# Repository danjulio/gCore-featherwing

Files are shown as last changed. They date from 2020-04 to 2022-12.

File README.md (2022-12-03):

Note: Check out my second version of [gCore](https://github.com/danjulio/gCore).

## gCore - A controller for portable GUI-based devices
gCore ("Gadget Core") is an ESP32 development board designed to mate with the [Adafruit TFT Featherwing](https://www.adafruit.com/product/3651) 480x320 pixel 3.5" TFT LCD display with resistive touch.  It contains a WROVER-B module, USB UART, true USB power-bath Li-Ion battery charger, a pair of ICR10440 batteries and a boost/buck 3.3V converter.  It is designed to support soft-power control and battery voltage/charge status monitoring.  A write-up exists on [hackaday.io](https://hackaday.io/project/170774-old-gcore-for-gui-based-gadgets).

gCore is released as open source hardware and supporting software under the GPLv3 license in hopes it will be helpful to others.  This repository contains two subdirectories.

1. hardware - contains eagle design files, gerber files, and documentation.
2. software - arduino library for power control, [LittlevGL](https://github.com/littlevgl) driver for Arduino and [FabGL](https://github.com/fdivitto/FabGL) port.

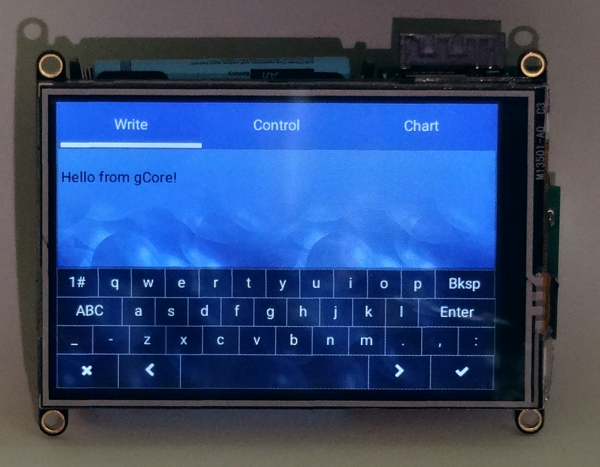
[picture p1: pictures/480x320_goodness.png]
gCore LittlevGL


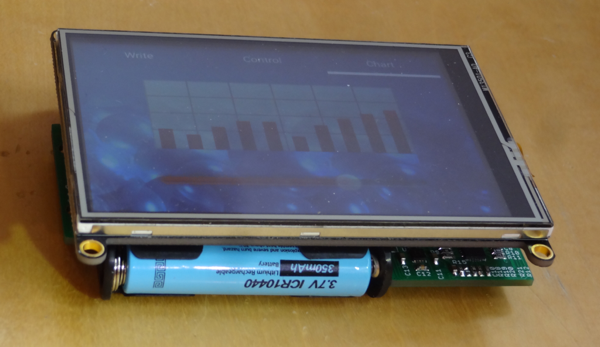
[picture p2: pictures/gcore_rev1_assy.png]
gCore


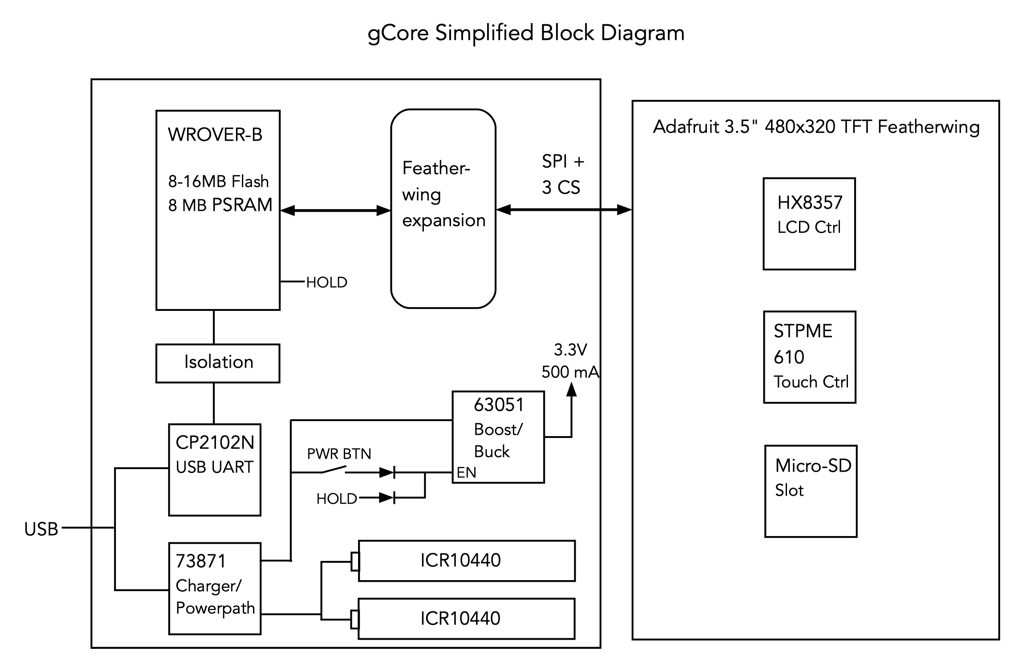
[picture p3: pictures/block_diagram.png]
gCore Block Diagram


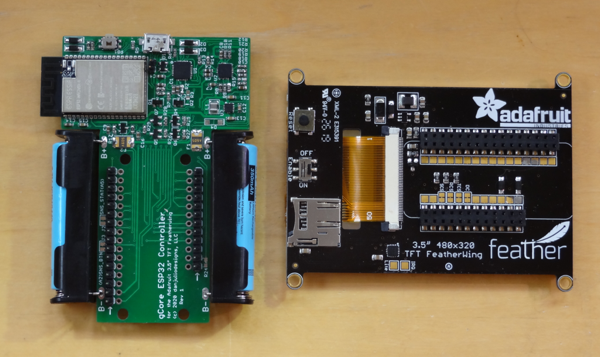
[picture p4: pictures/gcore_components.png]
gCore Components


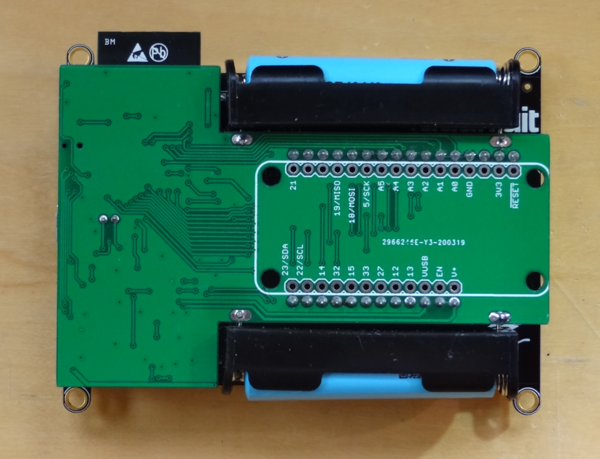
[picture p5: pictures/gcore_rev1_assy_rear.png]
gCore Rear


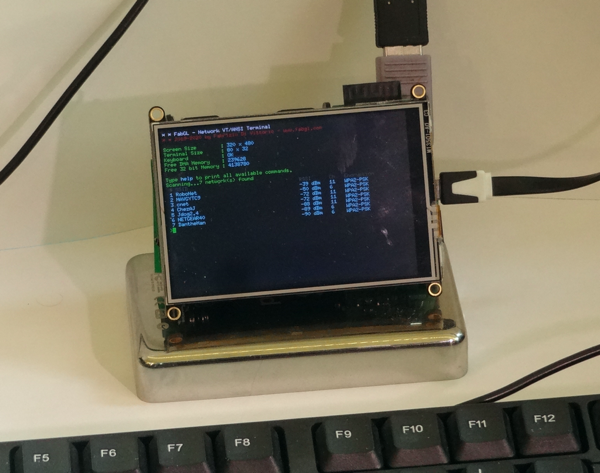
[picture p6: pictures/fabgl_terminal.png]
gCore FabGL


### gCore Operation
gCore is built around several components.

#### ESP32 Core
The ESP32 is a great micro-controller.  Powerful and inexpensive with a good amount of memory, WiFi, Bluetooth and full complement of peripherals.  Code can be written using Espressif's ESP IDF libraries and development environment or the ESP32 Arduino integration.  gCore uses a WROVER module because it also includes an external 8 MB PSRAM and up to 16 MB built-in flash enabling applications that require a lot of memory at the cost of two IO pins.

#### CP2102N USB UART
A Silicon Labs CP2102N USB UART provides access to the primary ESP32 serial port for programming and debug.  The RTS# and DTR# signals are interfaced to RESET# and IO0 in the traditional way so that external programming software can automatically upload new firmware.  While the ESP32 and other gCore devices are powered from its built-in power system, the CP2102 is powered by the USB port so that it does not add an additional load on the battery.  There is isolation circuitry to reduce sneak current paths between the two power domains.

The CP2102N CHRGEN and CHR0 signals are routed to the MCP73871 to allow for intelligent charge control based on the USB state.  These signals allow it to select a charge current of 0 mA when the USB Bus has been suspended (e.g. laptop sleeping), 100 mA when the USB Bus is running but the USB UART hasn't been enumerated yet or 500 mA when the USB Bus has been enumerated or gCore is connected to a dedicated USB Charger.  These features require the CP2102N be configured using software from Silicon Labs.  Please see the instructions in the Software/CP2102N subdirectory.

#### MCP73871 Load Sharing Charge Controller
A Microchip MCP73871 provides both the battery charging circuit and an intelligent power path that automatically routes power from USB, when available, to the Boost-Buck converter, augmenting it with power from the batteries when necessary.  This allows it to correctly identify when the batteries are charged (a problem with some other development boards that put the load on the same output that is charging the battery).  In addition the charge status signals are connected to a voltage divider network allowing the ESP32 to use an analog input to detect which of four states the charger is in.

* Charge Idle - Not charging.  Power either from USB or battery.
* Charging - Currently charging the battery
* Charge Done - Charging phase finished.  Power from USB.
* Fault - Charger detected a fault (see the spec sheet).

#### TPS63051 Boost-Buck Converter
A TI TPS63051 boost-buck converter provides gCore's 3.3V power supply at up to 500 mA.  Unlike many other development boards that only use a buck-converter (or inefficient linear regulator), it assures a valid 3.3V power supply even when the battery is depleted.  

#### Dual ICR10440 Li-Ion batteries
A pair of AAA-sized Li-Ion batteries allow for relatively thin enclosures.  The batteries are connected in parallel with each battery in series with a PTC to allow them to equalize during charge and discharge and protect from shorts.  They are capable of powering a device for a couple of hours of run-time.  Quality ICR10440 cells can be found on Amazon.  Since the charger can provide up to 450-500 mA when gCore is powered down always use two cells so the per-cell charge current doesn't exceed its recommended maximum.

A larger battery may also be used by connecting it to the terminals of one of the ICR10440 batteries.

**Update: See the note in the Hardware directory readme about issues with the dual battery system.** 

#### GPIO Utilization
| GPIO | Function | Notes |
|:----:|:---:|:-----:|
| IO5  |  SPI SCK | SPI CLK for TFT, Touchscreen and Micro-SD |
| IO14 | SD CS  | Micro-SD CS# on Adafruit TFT Featherwing |
| IO15 |  TFT CS  | TFT CS# on Adafruit TFT Featherwing |
| IO18 | SPI MOSI | SPI MOSI for TFT, Touchscreen and Micro-SD |
| IO19 | SPI MISO | SPI MISO for Touchscreen and Micro-SD |
| IO32 | TS CS  | Touchscreen CS# on Adafruit TFT Featherwing |
| IO33 |  TFT DC  | TFT DC on Adafruit TFT Featherwing |
| IO34 | SNS_BTN  | ESP ADC1_CH6/Arduino A2 Button sense analog input |
| IO35 | SNS_BATT | ESP ADC1_CH7 Battery voltage sense analog input |
| IO36 | SNS_STAT | ESP ADC1_CH0/Arduino A4 charge stat sense analog input |

Note that both the SNS\_BTN and SNS\_STAT signals include jumper pads with a cuttable link to disconnect them from the analog input in case their functionality is not needed or the analog input needs to be used for another purpose.  See the schematic in the hardware sub-directory for more detail.

The two featherwing signals normally used to bring out the second ESP32 UART on its IO16 and IO17 pins are not connected because these pins are used internally by the WROVER module to support the PSRAM.

IO14 is available if no Micro-SD Card is inserted into the TFT Featherwing.

#### Available GPIO
The following GPIO are not connected and are available for application use.

| GPIO | Notes |
|:----:|:-----:|
| IO4  | A5 |
| IO12 | |
| IO13 | |
| IO21 | |
| IO22 | SCL |
| IO23 | SDA |
| IO25 | A1 |
| IO26 | A0 |
| IO27 | |
| IO39 | A3 |

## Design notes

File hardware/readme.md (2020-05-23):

## gCore Hardware Documentation

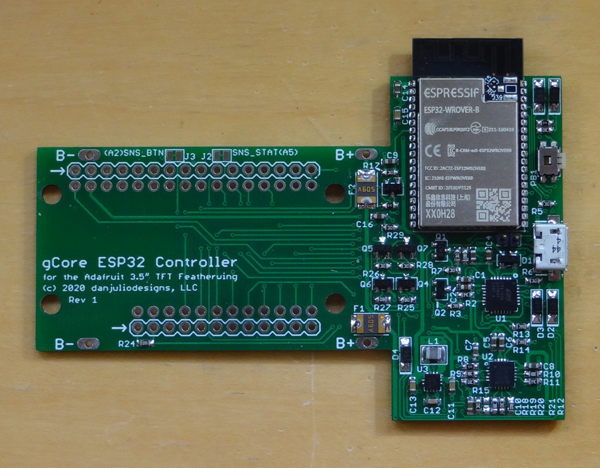
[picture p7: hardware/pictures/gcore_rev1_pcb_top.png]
gCore Rev 1 PCB


This directory contains the hardware design for gCore (Rev 2 design).

* documentation - BOM, schematic and board layout PDF renders, list of components to be loaded on the PCB.
* eagle - Eagle v7.7 design files
* gerber - Gerber files for PCB (not including stencil)
* stencil - Gerber files for top stencil

### Revision 2 Design Important Note
These files represent the second revision of the design.  To date I have only built the first revision and incorporated a few changes I found in Rev 2.  The changes were minor and I tested all of them with modifications (bodges) to the first revision. I am very confident that the second revision is correct and will work perfectly but in the spirit of full disclosure I'm letting you know.

#### Rev 2 PCB Top

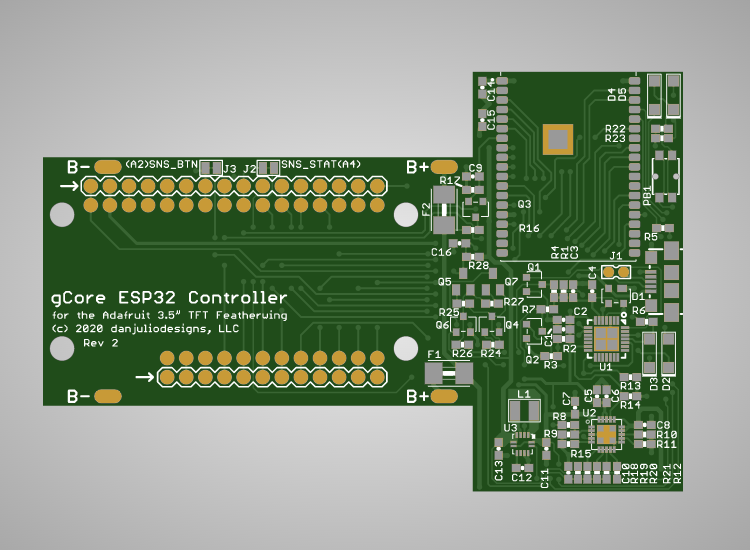
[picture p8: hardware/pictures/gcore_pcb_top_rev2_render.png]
Rev 2 PCB Top


#### Rev 2 PCB Bottom

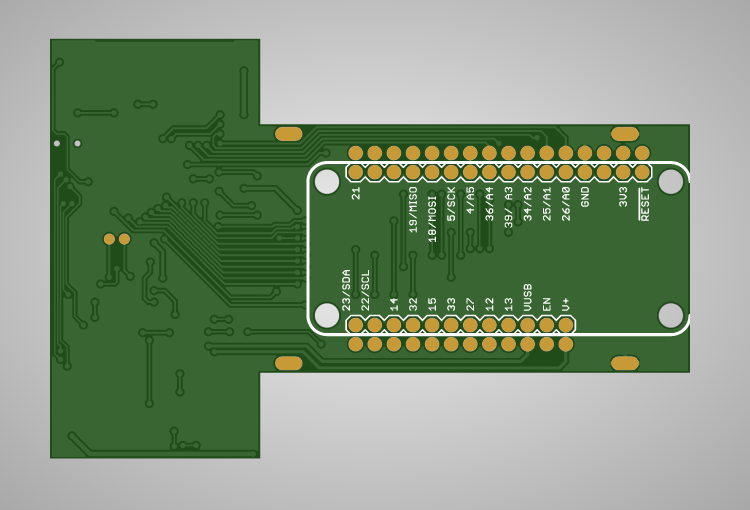
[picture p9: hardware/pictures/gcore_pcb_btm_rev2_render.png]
Rev 2 PCB Bottom


### Hardware Notes

1. Turn the power switch located on the Adafruit TFT LCD featherwing to the ON position.  This allows the LCD backlight to be lit when 3.3V power comes on and also provides the ability to use the GPIO2 output on the STMPE610 touchscreen controller to turn it on and off under software control.

2. The CHREN and CHR0 signals between U1 (CP2102N) and U2 (MCP73871) are designed to work in conjunction with reconfiguring U1 via Simplicity Studio Xpress Configurator to support USB Charger detection.  Do not stuff R13 and R14 if you will not reconfigure U1.  This enables charging  at 500 mA.

2. Cut J3 between the pads if you do not want the power button sense circuitry attached to an analog input or you wish to attach it to a different analog input (connect a wire from the right pad to the desired analog input).

4. Cut J4 between the pads if you do not want the charge status sense circuitry attached to an analog input or you wish to attach it to a different analog input (connect a wire from the right pad to the desired analog input).

5. Two pins (J6-14, J6-15) on the featherwing expansion port are not connected.  On Sparkfun and Adafruit ESP32 featherwings these are connected to ESP32 GPIO 16 and 17.  However these pins are not available on the gCore's WROVER-B module.  They are used internally for the 8 MB PSRAM.

6. J1 is an optional jumper between the two USB data lines.  It should not be necessary and was included in case you ever attach a power supply to gCore that does not short the data lines.  The CP2102N will enable charging because it thinks the bus is not enumerated and there is no charger attached.  But be sure to remove the jumper before connecting to a computer!

### Battery Notes
After using a pair of gCore prototypes for some time I found that one unit would no longer keep the batteries balanced and they would slowly discharge.  The other unit works fine.  Experimentation described in more detail on the hackaday.io project page was unsuccessful in explaining why so now I must add the caveat that using the dual ICR10440 battery solution may not work.  It's easy, however, to use a single battery, connected to one pair of battery terminals, with its PTC bypassed, and the AAA battery holders removed or not installed.

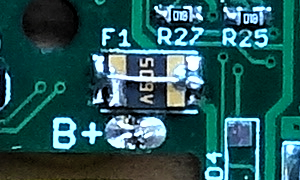
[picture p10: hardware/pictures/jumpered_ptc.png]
Jumpered PTC


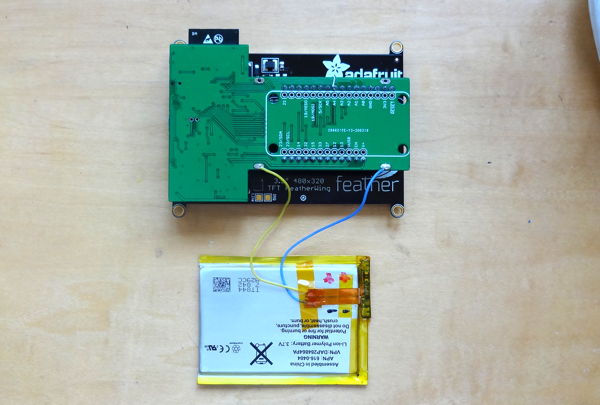
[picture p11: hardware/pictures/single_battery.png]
Single battery


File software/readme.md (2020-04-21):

## gCore software support

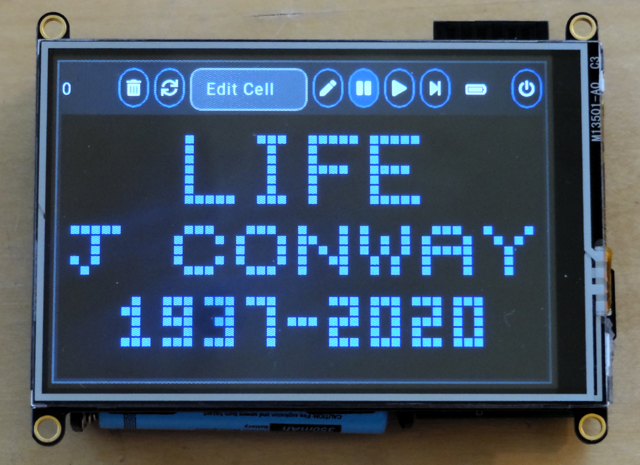
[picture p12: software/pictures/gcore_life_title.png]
Demo tribute to John Conway


This directory contains software support for gCore to provide TFT and touchscreen drivers and power management functions for both Arduino and ESP IDF development environments.  See each subdirectory for more information.

* Arduino - A pair of demos for ESP32 Arduino including gCore power management and [LittlevGL/Arduino](https://github.com/littlevgl/lv_arduino) integration.
* CP2102N - Instructions for enabling automatic USB charger detection in the Silicon Labs CP2102N USB UART.  This allows gCore to correctly set charge current levels based on the USB interface.
* FabGL - A port of Fabrizio Di Vittorio's fantasic [FabGL](https://github.com/fdivitto/FabGL) library to gCore.
* LittlevGL - A native v3.5 ESP-IDF demo project showing [Native LittlevGL](https://github.com/littlevgl/lvgl) integration.

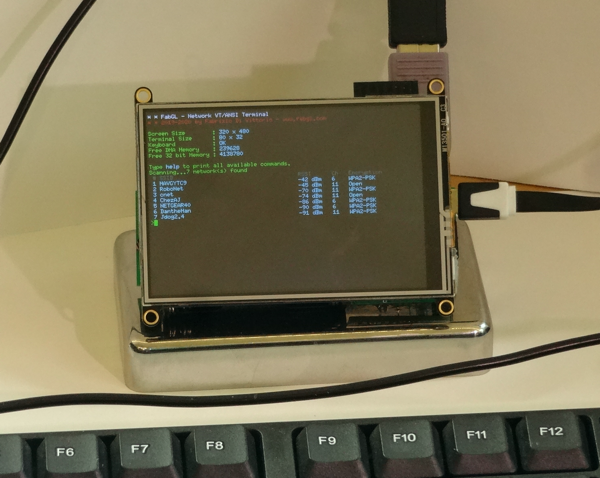
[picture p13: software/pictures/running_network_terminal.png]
A tiny VT100


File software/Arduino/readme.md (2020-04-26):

## gCore ESP32 Arduino

Two simple demos showing how to integrate gCore into ESP32 Arduino projects.  You will need to add ESP32 support to Arduino (see links below).

1. `gcore_power_demo` - Simple sketch that includes `gcore_power.ino` for power management (see below).  The sketch simply prints battery voltage, button press detection (short/long press) and charge state every second.  After 60 seconds a long press will power off (when the button is released).  After 120 seconds the sketch powers down automatically.

2. `lvgl_demo` - A port of the LittlevGL demo to arduino.  This sketch includes `tft.ino` and `ts.ino` along with the driver integration code for the Arduino version of LittlevGL to use the Adafruit TFT/touchscreen.  The demo also uses `gcore_power.ino` to provide automatic low-battery shutdown and shutdown on a long power button press.  You will need to add the LittlevGL library to Arduino.  I used v6.1.1 during development.

### Useful Links

* [Esspressif ESP32 Arduino github](https://github.com/espressif/arduino-esp32)
* [LittlevGL Arduino github](https://github.com/littlevgl/lv_arduino)

### gcore_power module API
The ```gcore_power``` module creates a separate FreeRTOS task to read the three analog inputs connected to gCore circuitry (battery voltage, button, and charge state), keep power-management related state and provide an API for use by user Arduino code (protected by a mutex).

`gcore_set_btn_pin(pin)` - Used to set a non-standard GPIO pin for the button analog input (if you cut J3 and wire to another analog input).  Call this before calling ```gcore_begin()```.  Does not need to be called to use the default input.

`gcore_set_stat_pin(pin)` - Used to set a non-standard GPIO pin for the status analog input (if you cut J4 and wire to another analog input).  Call this before calling `gcore_begin()`.  Does not need to be called to use the default input.
 
`gcore_begin()` - Initialize the power monitoring system.  Should be called during setup before calling other API routines (aside from the set_pin routines above).

`gcore_get_batt_voltage()` - Returns a float with the current battery voltage.  Note that the ESP32 internal vref is not highly precise and although the Arduino library attempts to use any built-in calibration constants this reading can be off by 100mV or so.

`gcore_set_low_voltage_threshold(volts)` - Set the automatic low-battery shutdown voltage specifying a float between 2.5 an 4.2.  The default is 3.4 volts.

`gcore_get_low_voltage_threshold()` - Returns a float with the current automatic low-battery shutdown voltage.

`gcore_set_low_voltage_duration(secs)` - Set the automatic low-battery shutdown interval specifying an integer number of seconds the battery voltage must be below the low voltage threshold.  The default is 10 seconds.

`gcore_get_low_voltage_duration()` - Returns an integer containing the automatic low-battery shutdown interval.

`gcore_button_down()` - Returns a bool indicating if the power button is currently detected in the pressed state.

`gcore_button_short_press()` - Returns a bool indicating if a short-press has been detected.  A short-press is detected when the power button is pressed and released before the button threshold seconds have elapsed.

`gcore_button_long_press()` - Returns a bool indicating if a long-press has been detected.  A long-press is detected when the power button is pressed at the point button threshold seconds have elapsed.

`gcore_set_button_shutdown_enable(en)` - Enable or disable power-off when a long-press is detected by passing in a true or false bool value.  When enabled power will be disabled when the power button is held for the button threshold seconds.  Note that because the button circuitry enables power while the button is pressed power will not actually be removed until the button is released.  This function enables the code to de-assert PWR_HOLD.  Power button power-off functionality is enabled by default.

`gcore_get_button_shutdown_enable()` - Returns a bool indicating if power button power-off functionality is enabled or not.

`gcore_set_button_threshold_duration(secs)` - Set the button threshold integer seconds used to differentiate between short and long press.  The default value is 2 seconds.

`gcore_get_button_threshold_duration()` - Return and integer containing the button threshold seconds.

`gcore_get_charge_state()` - Returns an integer indicating the current charge state.

* 0 - Charge Idle.  No external power source connected.
* 1 - Charge Complete.  Not charging but external power source connected.
* 2 - Charging.
* 3 - Charge Fault (see the MCP73871 specification).

`gcore_power_down()` - De-assert the PWR_HOLD signal to immediately powerdown gCore.

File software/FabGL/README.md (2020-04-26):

# FabGL

## gCore Modifications
This directory contains the modified FabGL code to work with gCore.  Primarily this includes adding support for the HX8357 TFT driver.  I had to modify FabGL to support a higher resolution TFT display (480x320) that included a new buffer scheme because the existing software architecture caused the ESP32 to run out of memory at that resolution; as well as modify the terminal to support more than 25 lines.

* `src/fabglconf.h` - Added a modeline for 480x320 pixel TFT display.
* `src/terminal.cpp` - Added support for a maximum of 32 lines.
* `src/dispdrivers/TFTControllerGeneric.cpp` - Many changes including reducing SPI frequency to 26 MHz and modifying the SPI transactions, changing malloc allocation to use a different buffer scheme and fixing a bug in the TFT orientation code.
* `src/dispdrivers/TFTControllerGeneric.h` - Added new DMA buffer.
* `src/dispdrivers/TFTControllerSpecific.cpp` - Added support for HX8357 TFT driver.
* `src/dispdrivers/TFTControllerSpecific.h` - Added support for HX8357 TFT driver.

The examples in this directory were ported to gCore.  I used GPIO13 for PS/2 keyboard data and GPIO27 for PS/2 keyboard clock wired the way Fabrizio recommends.  The examples here also include the gCore power management functionality with automatic low-battery shutdown and soft power off by pressing and holding the power button.

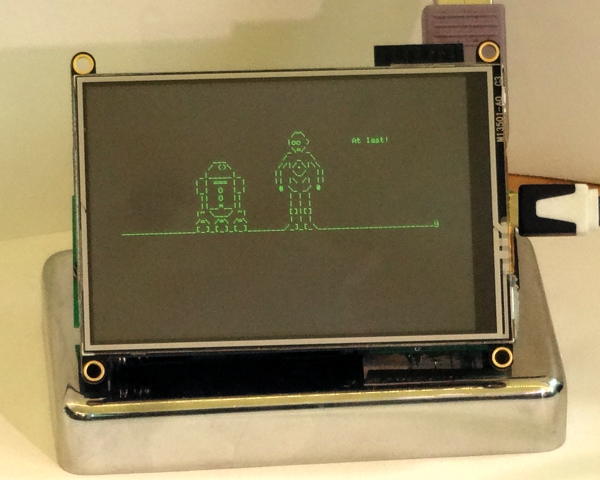
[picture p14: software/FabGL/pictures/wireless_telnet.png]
A very famous telnet


## Original FabGL README contents
### Display Controller, PS/2 Mouse and Keyboard Controller, Graphics Library, Sound Engine, Graphical User Interface (GUI), Game Engine and ANSI/VT Terminal for the **ESP32**

**[Please look here for full API documentation](http://www.fabglib.org)**

If you would like to **support FabGL's development**, please see the [**Donations page**][Donations].
You can also support me getting my own [development board](https://www.tindie.com/products/fabgl/fabgl-development-board/).

This library works with ESP32 revision 1 or upper. See [**Compatible Boards**][Boards].

FabGL is mainly a Graphics Library for ESP32. It implements several display drivers (for direct VGA output and for I2C and SPI LCD drivers).
FabGL can also get input from a PS/2 Keyboard and a Mouse. FabGL implements also: an Audio Engine, a Graphical User Interface (GUI), a Game Engine and an ANSI/VT Terminal.

This library works with ESP32 revision 1 and upper.

VGA output requires a digital to analog converter (DAC): it can be done by three 270 Ohm resistors to have 8 colors, or by 6 resistors to have 64 colors.

There are several fixed and variable width fonts embedded.

Unlimited number of sprites are supported. However big sprites and a large amount of them reduces the frame rate and could generate flickering.

When there is enough memory (on low resolutions like 320x200), it is possible to allocate two screen buffers, so to implement double buffering.
In this case primitives are always drawn on the back buffer.

Except for double buffering or when explicitly disabled, all drawings are performed on vertical retracing (using VGA driver), so no flickering is visible.
If the queue of primitives to draw is not processed before the vertical retracing ends, then it is interrupted and continued at next retracing.

There is a graphical user interface (GUI) with overlapping windows and mouse handling and a lot of widgets (buttons, editboxes, checkboxes, comboboxes, listboxes, etc..).

Finally, there is a sound engine, with multiple channels mixed to a mono output. Each channel can generate sine waveforms, square, etc... or custom sampled data.

### Installation Tutorial (click for video):

Everything Is AWESOME (https://www.youtube.com/watch?v=8OTaPQlSTas "")

### Space Invaders Example (click for video):

Everything Is AWESOME (https://www.youtube.com/watch?v=LL8J7tjxeXA "")

### Graphical User Interface - GUI (click for video):

Everything Is AWESOME (https://www.youtube.com/watch?v=84ytGdiOih0 "")

### Sound Engine (click for video):

Everything Is AWESOME (https://www.youtube.com/watch?v=RQtKFgU7OYI "")

### Altair 8800 emulator - CP/M text games (click for video):

Everything Is AWESOME (https://www.youtube.com/watch?v=y0opVifEyS8 "")

### Commodore VIC20 emulator (click for video):

Everything Is AWESOME (https://www.youtube.com/watch?v=ZW427HVWYys "")

### Simple Terminal Out Example (click for video):

Everything Is AWESOME (https://www.youtube.com/watch?v=AmXN0SIRqqU "")

### Network Terminal Example (click for video):

Everything Is AWESOME (https://www.youtube.com/watch?v=n5c27-y5tm4 "")

### Modeline Studio Example (click for video):

Everything Is AWESOME (https://www.youtube.com/watch?v=Urp0rPukjzE "")

### Loopback Terminal Example (click for video):

Everything Is AWESOME (https://www.youtube.com/watch?v=hQhU5hgWdcU "")

### Double Buffering Example (click for video):

Everything Is AWESOME (https://www.youtube.com/watch?v=TRQcIiWQCJw "")

### Collision Detection Example (click for video):

Everything Is AWESOME (https://www.youtube.com/watch?v=q3OPSq4HhDE "")

[Donations]: https://github.com/fdivitto/FabGL/wiki/Donations
[Boards]: https://github.com/fdivitto/FabGL/wiki/Boards

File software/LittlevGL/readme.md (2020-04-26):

## gCore native LittlevGL Demo
This demo shows native LittlevGL integration along with a version of the gCore power management functions into the native Esspressif IDF.  It is based on the [ESP32 port of LittlevGL](https://github.com/littlevgl/lv_port_esp32).  Along with the demo application the gCore specific parts include the TFT and Touchscreen drivers and power management functions.

[John Conway](https://en.wikipedia.org/wiki/John_Horton_Conway), father of the Game of Life program, passed away due to complications from the COVID-19 virus while I was deciding what demo to write to show off gCore and LittlevGL.  This demo is my tribute to him and his many contributions to the fields of mathematics and computer science.

I built this demo using v3.5 of the [ESP IDF](https://github.com/espressif/esp-idf).  It should compile with no or few changes in the v4.X version.  It uses various LittlevGL controls such as buttons, drop-down menu, labels and canvas.  It's best used with a plastic pointer designed for resistive touch screens (especially when editing individual cells).

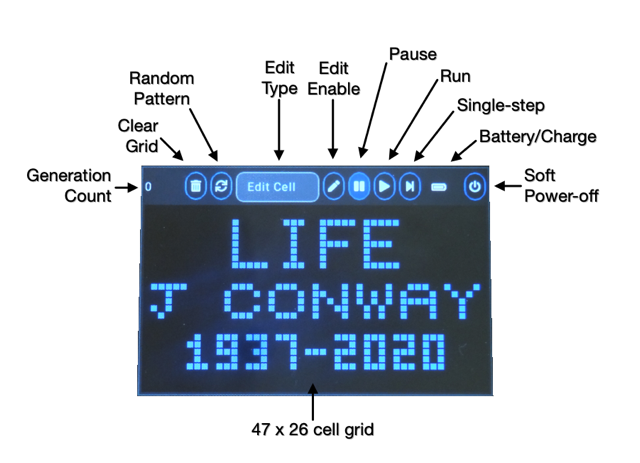
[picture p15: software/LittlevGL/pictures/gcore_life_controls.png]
gCore Life Controls


gCore Life implements Conway's original [Life](https://en.wikipedia.org/wiki/Conway%27s_Game_of_Life) algorithm.  It also includes a bunch of classic life cell collections that made interesting objects such as "gliders", a "glider gun", "spaceships" and more that can be added to the grid.  It's pretty demanding of the LittlevGL rendering system and gets about 6 generations/second although the actual Life alorithm is very fast.

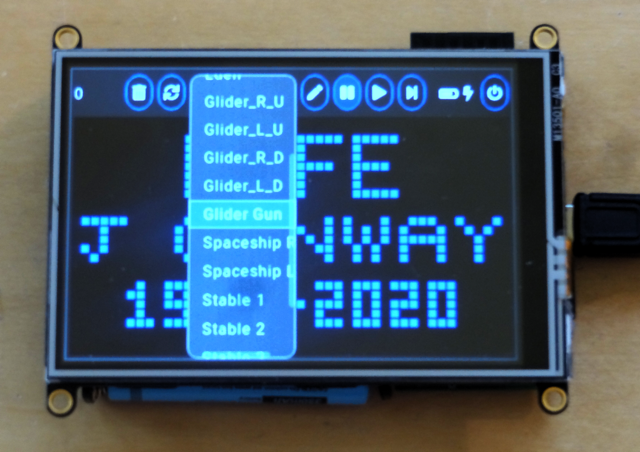
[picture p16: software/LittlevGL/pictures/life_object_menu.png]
Life Object menu


A "glider gun" above a left moving "spaceship".

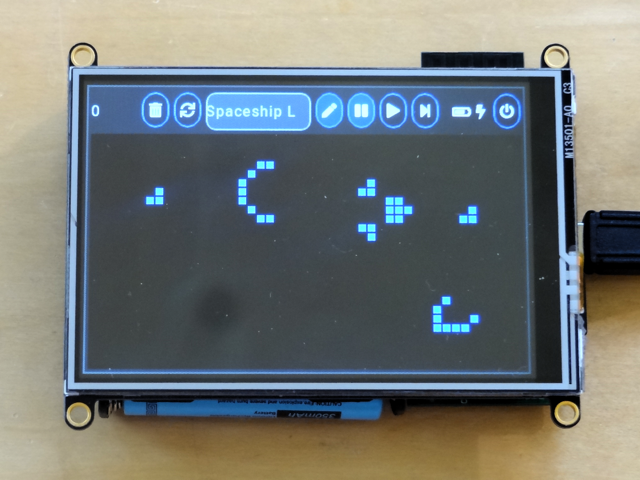
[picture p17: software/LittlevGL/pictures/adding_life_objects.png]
About to blow away a spaceship


### gCore power management functions
These functions are almost identical to those documented in the Arduino directory of this repository.  The only change is that `gcore_get_charge_state()` returns a `gcore_charge_t` enum value as shown in `gcore_power.h`.

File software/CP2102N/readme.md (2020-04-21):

## CP2102N Configuration
The Silicon Labs CP2102N USB UART used by gCore supports the ability to automatically identify USB Chargers and use that information along with information about the USB Bus enumeration (when plugged into a computer) to indicate the amount of current that legally can be taken from the USB bus on a pair of signals (CHREN and CH0).

* No current allowed - USB Suspended (e.g. laptop sleeping)
* 100 mA max - Un-enumerated USB Bus
* 500 mA max - Enumerated bus or USB Charger detected

These signals are connected to the MCP73871 charge controller on gCore (note: see the note in the hardware directory about how to enable charging if you do not reconfigure the CP2102N as shown here).  The charge controller is configured to supply a maximum of 0 mA, 100 mA or about 500 mA to both batteries for charging depending on the state of these signals.

Unfortunately this functionality is not enabled by default.  The instructions in the included Silicon Labs app note `AN721.pdf` show how to download and install a utility or the Simplicity Studio development environment that allows reconfiguration of the CP2102N via its USB interface and Silicon Labs Xpress Configurator.

The following changes need to be made via Xpress Configurator:

1. Reconfigure the maximum USB Current to 500 mA.
2. Enable Battery Charging functionality with a maximum current of 500 mA.

The images below show the changes I make to the default values read from the CP2102N by Xpress Configurator.

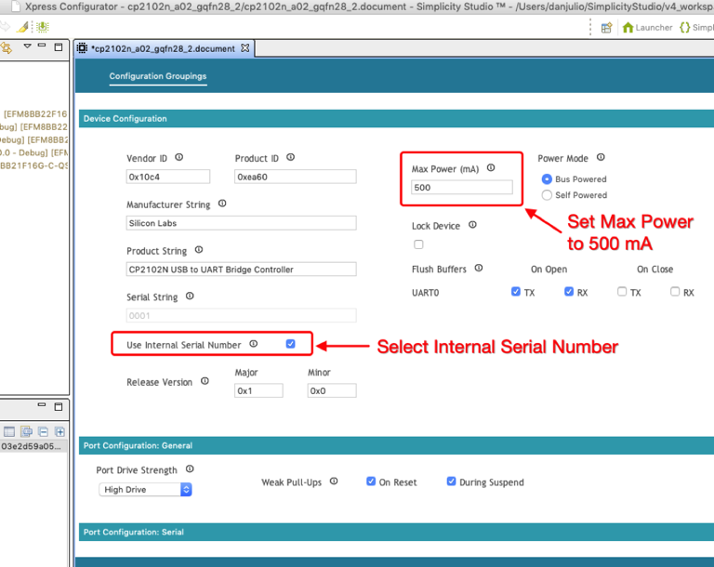
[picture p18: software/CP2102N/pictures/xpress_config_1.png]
First set of changes


For some reason the version of the Xpress Configurator I used from within Simplicity Studio did not automatically check the "User Internal Serial Number" button.  You need to do this if you wish to keep the factory-programmed serial number in each CP2102N.

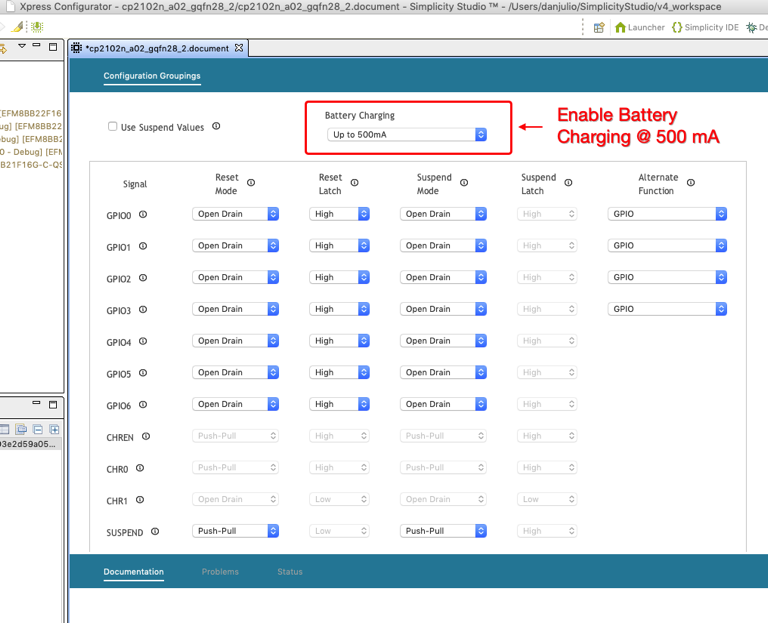
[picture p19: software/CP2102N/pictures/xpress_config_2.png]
Second set of changes


After making the changes it is a quick process to program them to the device.

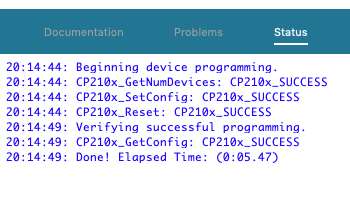
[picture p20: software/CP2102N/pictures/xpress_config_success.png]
programming success


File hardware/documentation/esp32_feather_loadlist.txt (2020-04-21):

ESP32 Featherwing Loadlist - Rev 2

Part     Value               Device               Package             Library             Sheet
A1       ESP32-WROVER-I      ESP32-WROVER-I       XCVR_ESP32-WROVER-I ESP32-WROVER-I      2

C1       4.7 uF              C-USSMT0603          C0603               djd_eagle_library   1
C3       4.7 uF              C-USSMT0603          C0603               djd_eagle_library   1
C5       4.7 uF              C-USSMT0603          C0603               djd_eagle_library   1
C6       4.7 uF              C-USSMT0603          C0603               djd_eagle_library   1
C7       4.7 uF              C-USSMT0603          C0603               djd_eagle_library   1
C8       4.7 uF              C-USSMT0603          C0603               djd_eagle_library   1

C2       0.1 uF              C-USSMT0603          C0603               djd_eagle_library   1
C4       0.1 uF              C-USSMT0603          C0603               djd_eagle_library   1
C9       0.1 uF              C-USSMT0603          C0603               djd_eagle_library   1
C10      0.1 uF              C-USSMT0603          C0603               djd_eagle_library   1
C14      0.1 uF              C-USSMT0603          C0603               djd_eagle_library   2
C16      0.1 uF              C-USSMT0603          C0603               djd_eagle_library   2

C11      22 uF               C-USSMT0603          C0603               djd_eagle_library   2
C13      22 uF               C-USSMT0603          C0603               djd_eagle_library   2
C15      22 uF               C-USSMT0603          C0603               djd_eagle_library   2

C12      1 nF                C-USSMT0603          C0603               djd_eagle_library   2

CON1                         USBMICROB            USB_MICROB_SMT      djd_eagle_library   1

D1       SP0503BAHTG         SP0503BAHTG          SOT143              djd_eagle_library   1

D2       SD103               DIODESMT_SOD123      SOD123              djd_eagle_library   1
D3       SD103               DIODESMT_SOD123      SOD123              djd_eagle_library   1
D4       SD103               DIODESMT_SOD123      SOD123              djd_eagle_library   2
D5       SD103               DIODESMT_SOD123      SOD123              djd_eagle_library   2

F1       MF-MSMF050          PTCFUSE-1812         1812                adafruit            1
F2       MF-MSMF050          PTCFUSE-1812         1812                adafruit            1

J1       332-02              332-02               332-02              con-garry           1

L1       1.5 uH              INDUCTORSMT1008      L1008               djd_eagle_library   2

PB1      436351045816        PB_TACT_4WS          WURTH_WS_TASU_TACT  djd_eagle_library   2

Q1       NX7002AKVL          MOSFET-NCHANNELSOT23 SOT23-3             djd_eagle_library   1
Q2       NX7002AKVL          MOSFET-NCHANNELSOT23 SOT23-3             djd_eagle_library   1
Q3       NX7002AKVL          MOSFET-NCHANNELSOT23 SOT23-3             djd_eagle_library   1
Q4       NX7002AKVL          MOSFET-NCHANNELSOT23 SOT23-3             djd_eagle_library   2
Q6       NX7002AKVL          MOSFET-NCHANNELSOT23 SOT23-3             djd_eagle_library   2

Q5       MMBT3904-7-F        BC808-NPN-SOT23-BEC  SOT23-BEC           transistor          2
Q7       MMBT3904-7-F        BC808-NPN-SOT23-BEC  SOT23-BEC           transistor          2

R1       1 kohm              R-USSMT0603          R0603               djd_eagle_library   1
R12      1 kohm              R-USSMT0603          R0603               djd_eagle_library   1
R24      1 kohm              R-USSMT0603          R0603               djd_eagle_library   2
R26      1 kohm              R-USSMT0603          R0603               djd_eagle_library   2

R2       22.1 kohm           R-USSMT0603          R0603               djd_eagle_library   1
R11      22.1 kohm           R-USSMT0603          R0603               djd_eagle_library   1

R3       47.5 kohm           R-USSMT0603          R0603               djd_eagle_library   1
R13      47.5 kohm           R-USSMT0603          R0603               djd_eagle_library   1
R14      47.5 kohm           R-USSMT0603          R0603               djd_eagle_library   1

R4       10 kohm             R-USSMT0603          R0603               djd_eagle_library   1
R5       10 kohm             R-USSMT0603          R0603               djd_eagle_library   1
R6       10 kohm             R-USSMT0603          R0603               djd_eagle_library   1
R7       10 kohm             R-USSMT0603          R0603               djd_eagle_library   1
R15      10 kohm             R-USSMT0603          R0603               djd_eagle_library   1
R17      10 kohm             R-USSMT0603          R0603               djd_eagle_library   1
R18      10 kohm             R-USSMT0603          R0603               djd_eagle_library   1
R21      10 kohm             R-USSMT0603          R0603               djd_eagle_library   1
R23      10 kohm             R-USSMT0603          R0603               djd_eagle_library   2
R25      10 kohm             R-USSMT0603          R0603               djd_eagle_library   2
R27      10 kohm             R-USSMT0603          R0603               djd_eagle_library   2
R28      10 kohm             R-USSMT0603          R0603               djd_eagle_library   2

R8       40.2 kohm           R-USSMT0603          R0603               djd_eagle_library   1
R16      40.2 kohm           R-USSMT0603          R0603               djd_eagle_library   1
R22      40.2 kohm           R-USSMT0603          R0603               djd_eagle_library   2

R9       15 kohm             R-USSMT0603          R0603               djd_eagle_library   1
R20      15 kohm             R-USSMT0603          R0603               djd_eagle_library   1

R10      2 kohm              R-USSMT0603          R0603               djd_eagle_library   1

R19      DNP                 R-USSMT0603          R0603               djd_eagle_library   1

U1       CP2102N-A02-GQFN28R CP2102N_QFN28        QFN28               djd_eagle_library   1
U2       MCP73871            MCP73871             QFN20               adafruit            1
U3       TPS63051            TPS63051_QFN         HOTROD_QFN12        djd_eagle_library   2

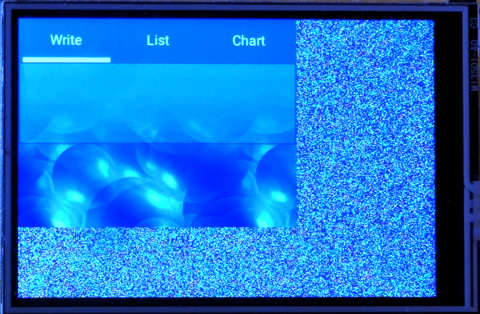
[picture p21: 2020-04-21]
pictures/why_bigger_display.png

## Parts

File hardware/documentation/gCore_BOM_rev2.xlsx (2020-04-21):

Line No | Qty | Ref Desg | Part Number | Manuf | Package/Type | Desc | Distributor Part Number | Notes
1 | 1 | A1 | ESP32-WROVER-B(16MB) | Espressif | SMT | WiFi Module ESP32-D0WD 64Mbit PSRAM 16MB SPI flash PCB Antenna | Mouser 356-ESP32-WROB(16MB | Can substitute other WROVER modules
2 | 6 | C1, C3, C5, C6, C7, C8 | JMK107BJ475KA-T | Taiyo Yuden | SMD/0603 | Multilayer Ceramic Capacitors MLCC - SMD/SMT 4.7uF 6.3V X5R 0603+/-10% | Mouser 963-JMK107BJ475KA-T | Can substitute equal or better
3 | 6 | C2, C4, C9, C10, C14, C16 | EMK107B7104KAHT | Taiyo Yuden | SMD/0603 | Multilayer Ceramic Capacitors MLCC - SMD/SMT 0.1uF 16V X7R 10% | Mouser 963-EMK107B7104KAHT | Can substitute equal or better
4 | 3 | C11, C13, C15 | GRM188R60J226MEA0D | Murata | SMD/0603 | Multilayer Ceramic Capacitors MLCC - SMD/SMT 0603 22uF 6.3volts | Mouser 81-GRM188R60J226ME0D | Can substitute equal or better
5 | 1 | C12 | C0603C102K3RACTU | Kemet | SMD/0603 | Multilayer Ceramic Capacitors MLCC - SMD/SMT 25V 1000pF 0603 X7R 10% | Mouser 80-C0603C102K3R | Can substitute equal or better
6 | 1 | CON1 | 47346-0001 | Molex | SMD | USB Connectors MICRO USB B RECPT BTTM MOUNT ASSY | Mouser 538-47346-0001
7 | 1 | D1 | SP0503BAHTG | Littelfuse | SMD/SOT143 | ESD Suppressors / TVS Diodes TVS AVAL DIODE SMT | Mouser 576-SP0503BAHTG
8 | 4 | D2, D3, D4, D5 | SD103CW RHG | Taiwan Semiconductor | SMD/SOD123 | Schottky Diodes & Rectifiers SOD-123 20V 0.35A Schottky Diode | Mouser 821-SD103CWRHG | Can substitute equal or better
9 | 2 | F1, F2 | MF-MSMF050-2 | Bourns | SMD/1812 | Resettable Fuses - PPTC 0.50A 15V 0.15ohm | Mouser 652-MF-MSMF050-2
10 | 1 | J1 | TMM-102-03-L-S | Samtec | TH | Headers & Wire Housings 2.00 mm Low Profile Terminal Strip | Mouser 200-TMM10203LS | Can substitute equal or better
11 | 1 | L1 | 1269AS-H-1R5M=P2 | Murata | SMD/1008 | Fixed Inductors 1.5uH 108mOhms2.1A +/-20% 2.5x2.0x1.0mm | Mouser 81-1269AS-H-1R5MP2
12 | 1 | PB1 | 436351045816 | Wurth Elektronik | SMT | Tactile Switches Tact Switch SMT 1.65mm White Act. | Mouser 710-436351045816
13 | 5 | Q1, Q2, Q3, Q4, Q6 | NX7002AKVL | Nexperia | SMD/SOT23 | MOSFET 60V SGL N-CH TRENCHMOS | Mouser 771-NX7002AKVL | Can substitute equal or better
14 | 2 | Q5, Q7 | MMBT3904-7-F | Diodes Incorporated | SMD/SOT23 | Bipolar Transistors - BJT 40V NPN SS Trans 60Vceo 6Vebo 200mA | Mouser 621-MMBT3904-F | Can substitute equal or better
15 | 4 | R1, R12, R24, R26 | RC0603FR-071KL | Yageo | SMD/0603 | Thick Film Resistors - SMD 1K OHM 1% | Mouser 603-RC0603FR-071KL | Can substitute equal or better
16 | 2 | R2, R11 | RC0603FR-0722K1L | Yageo | SMD/0603 | Thick Film Resistors - SMD 22.1K OHM 1% | Mouser 603-RC0603FR-0722K1L | Can substitute equal or better
17 | 3 | R3, R13, R14 | RC0603FR-0747K5L | Yageo | SMD/0603 | Thick Film Resistors - SMD 47.5K OHM 1% | Mouser 603-RC0603FR-0747K5L | Can substitute equal or better
18 | 12 | R4, R5, R6, R7, R15, R17, R18, R21, R23, R25, R27, R28 | RC0603FR-0710KL | Yageo | SMD/0603 | Thick Film Resistors - SMD 10K OHM 1% | Mouser 603-RC0603FR-0710KL | Can substitute equal or better
19 | 3 | R8, R16, R22 | RC0603FR-0740K2L | Yageo | SMD/0603 | Thick Film Resistors - SMD 40.2K OHM 1% | Mouser 603-RC0603FR-0740K2L | Can substitute equal or better
20 | 2 | R9, R20 | RC0603FR-0715KL | Yageo | SMD/0603 | Thick Film Resistors - SMD 15K OHM 1% | Mouser 603-RC0603FR-0715KL | Can substitute equal or better
21 | 1 | R10 | RC0603FR-072KL | Yageo | SMD/0603 | Thick Film Resistors - SMD 2K OHM 1% | Mouser 603-RC0603FR-072KL | Can substitute equal or better
22 | 1 | R19 |  |  |  |  |  | Do Not Populate
23 | 1 | U1 | CP2102N-A02-GQFN28R | Silicon Laboratories | SMD/QFN28 | USB Interface IC USB to UART bridge - QFN28 | Mouser 634-CP2102NA02QFN28R
24 | 1 | U2 | MCP73871-2CCI/ML | Microchip | SMD/QFN20 | Battery Management USB/AC Battery Charger | Mouser 579-MCP73871-2CCI/ML
25 | 1 | U3 | TPS63051RMWR | Texas Instruments | SMD/QFN12 | Switching Voltage Regulators | Mouser 595-TPS63051RMWR
26 | 2 | - | 2466 | Keystone Electronics | TH | Cylindrical Battery Contacts Clips Holders & Springs AAA P.C.B HOLDER | Mouser 534-2466 | Battery holder
27 | 1 | - | M22-1900005 | Harwin | TH | Headers & Wire Housings JUMPER SOCKET OPEN TOP BLACK GOLD | Mouser 855-M22-1900005 | Optional jumper header for J1

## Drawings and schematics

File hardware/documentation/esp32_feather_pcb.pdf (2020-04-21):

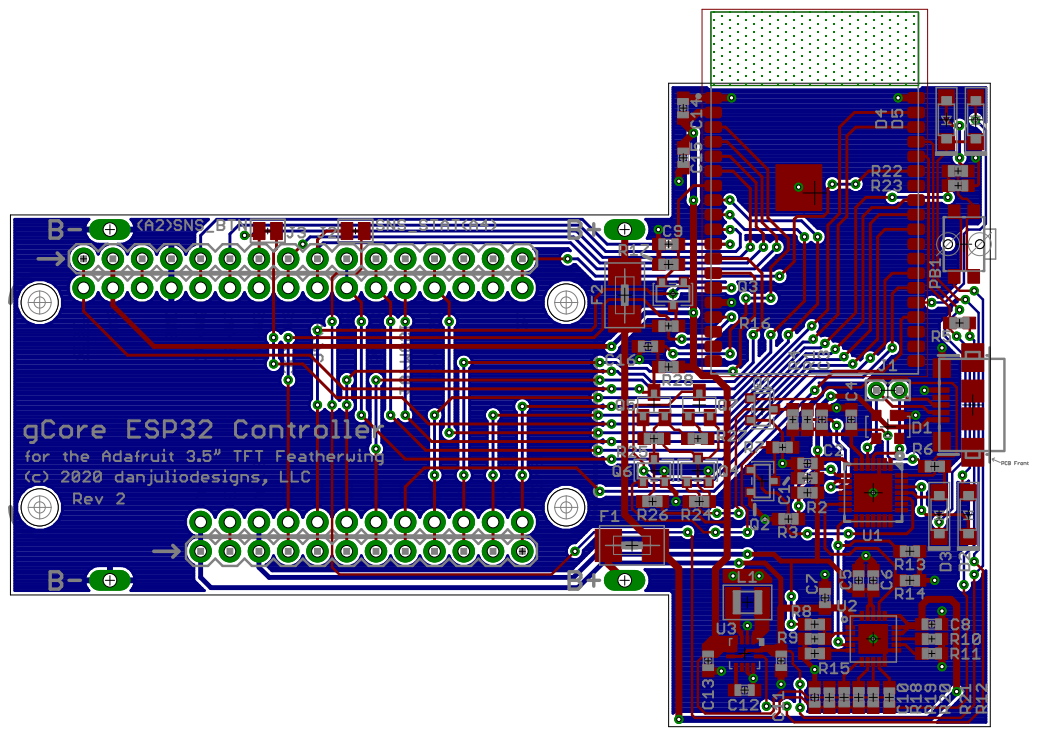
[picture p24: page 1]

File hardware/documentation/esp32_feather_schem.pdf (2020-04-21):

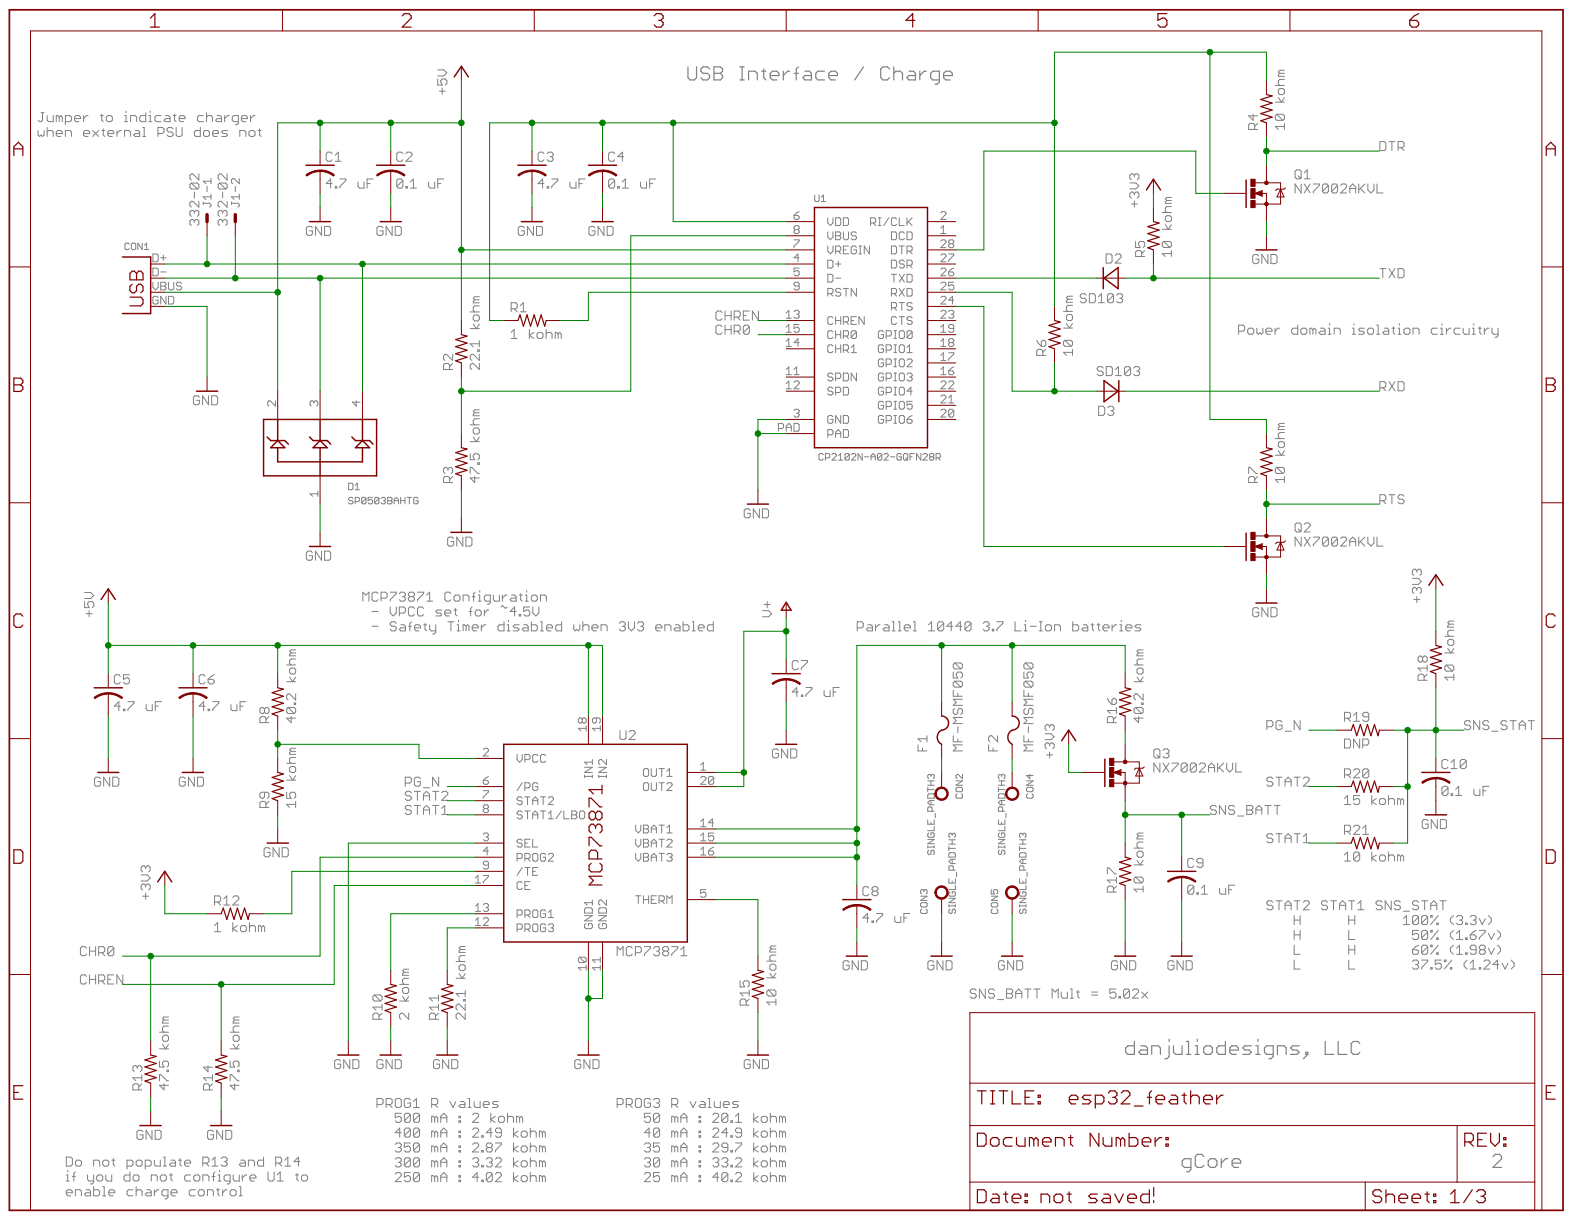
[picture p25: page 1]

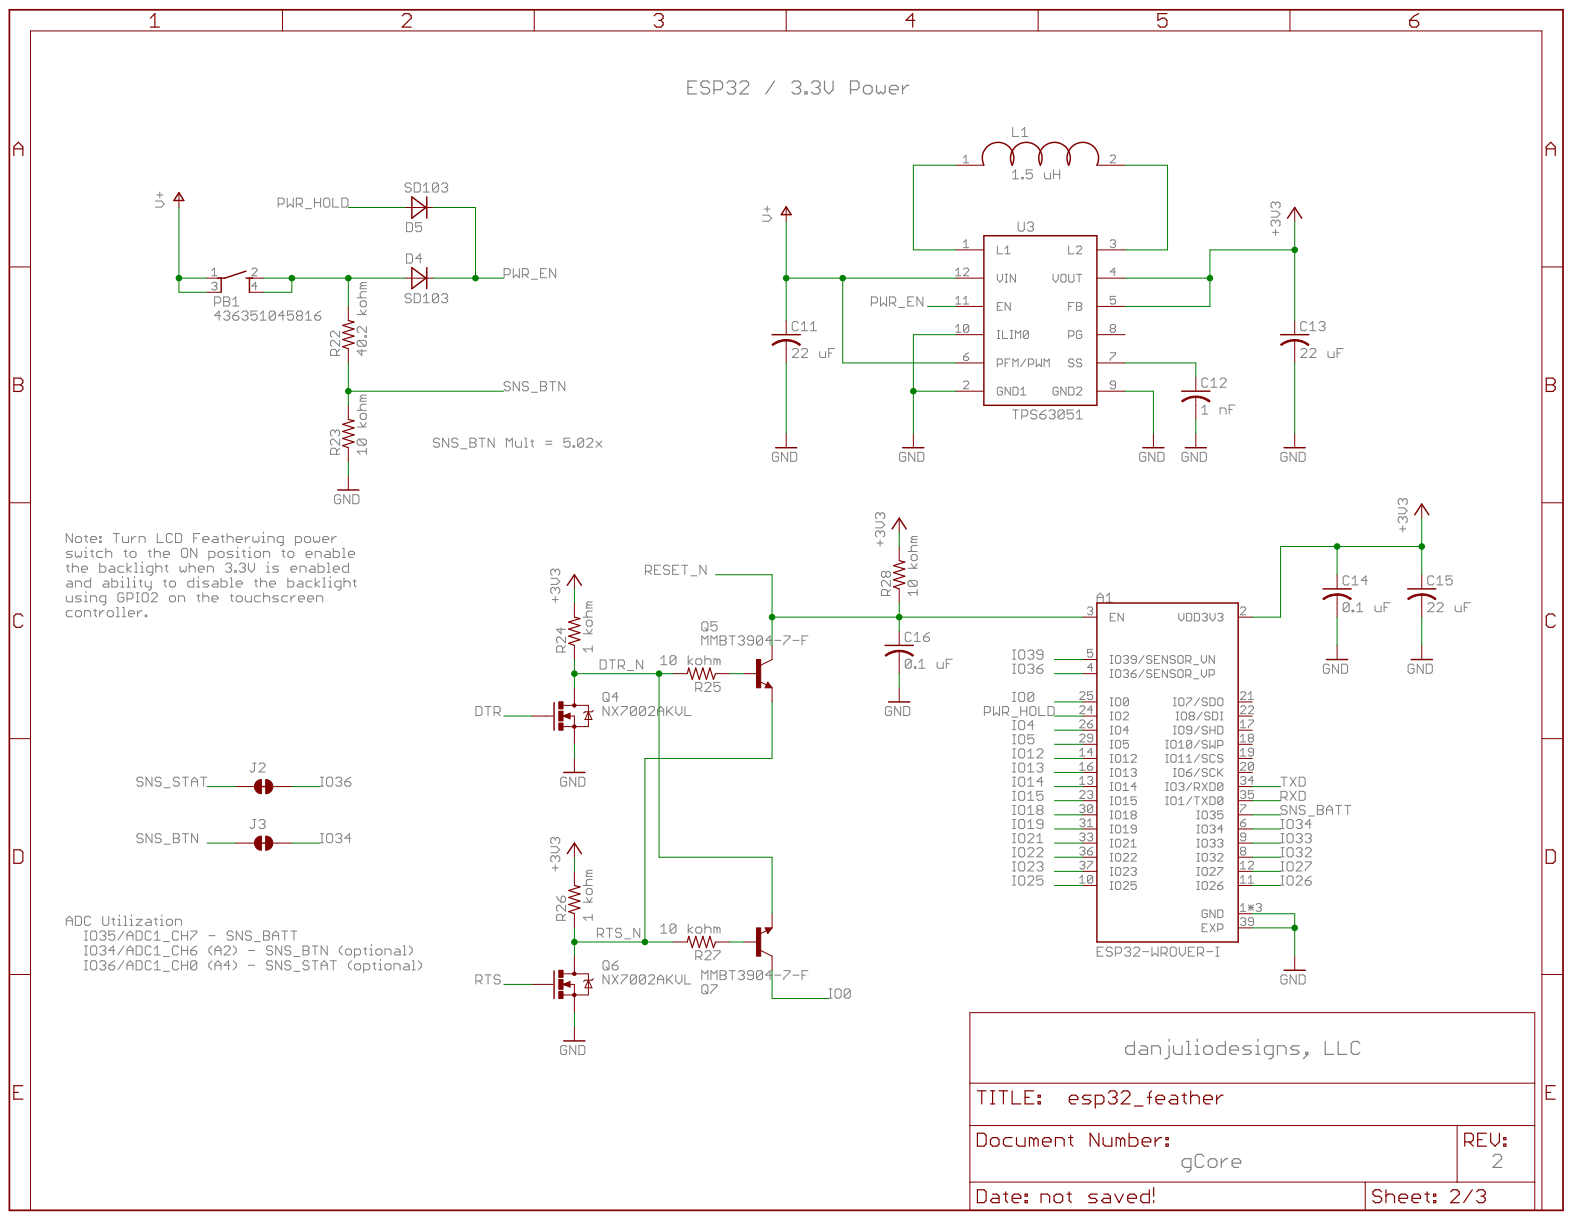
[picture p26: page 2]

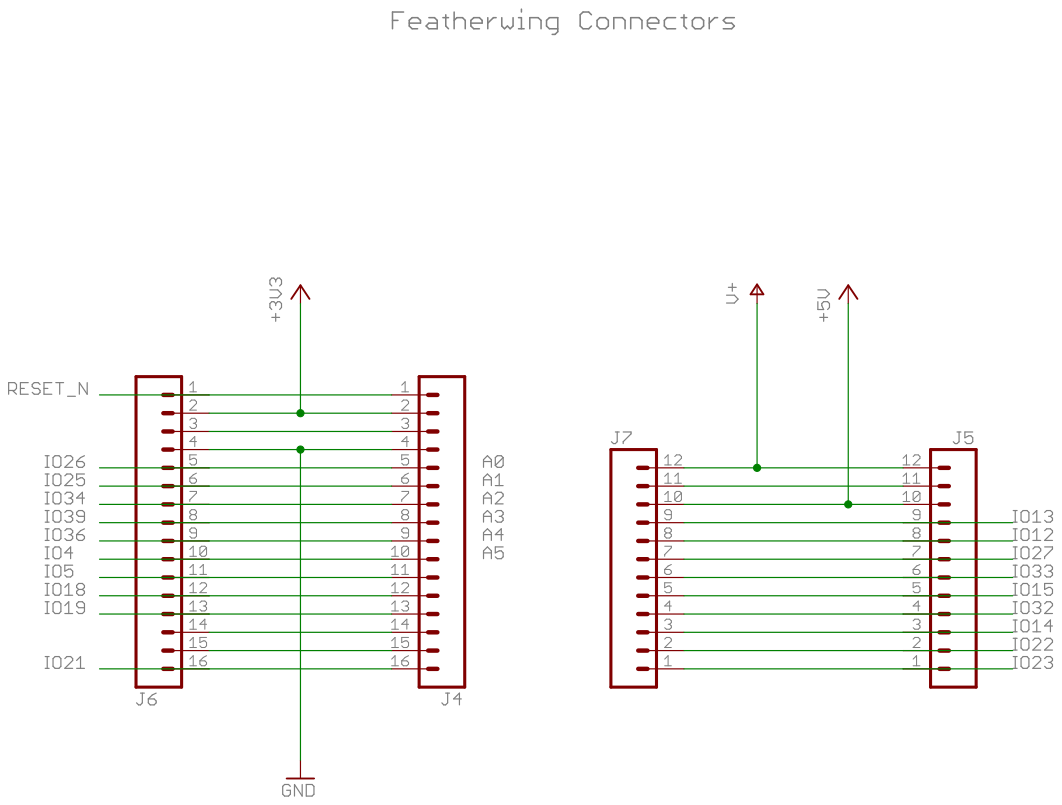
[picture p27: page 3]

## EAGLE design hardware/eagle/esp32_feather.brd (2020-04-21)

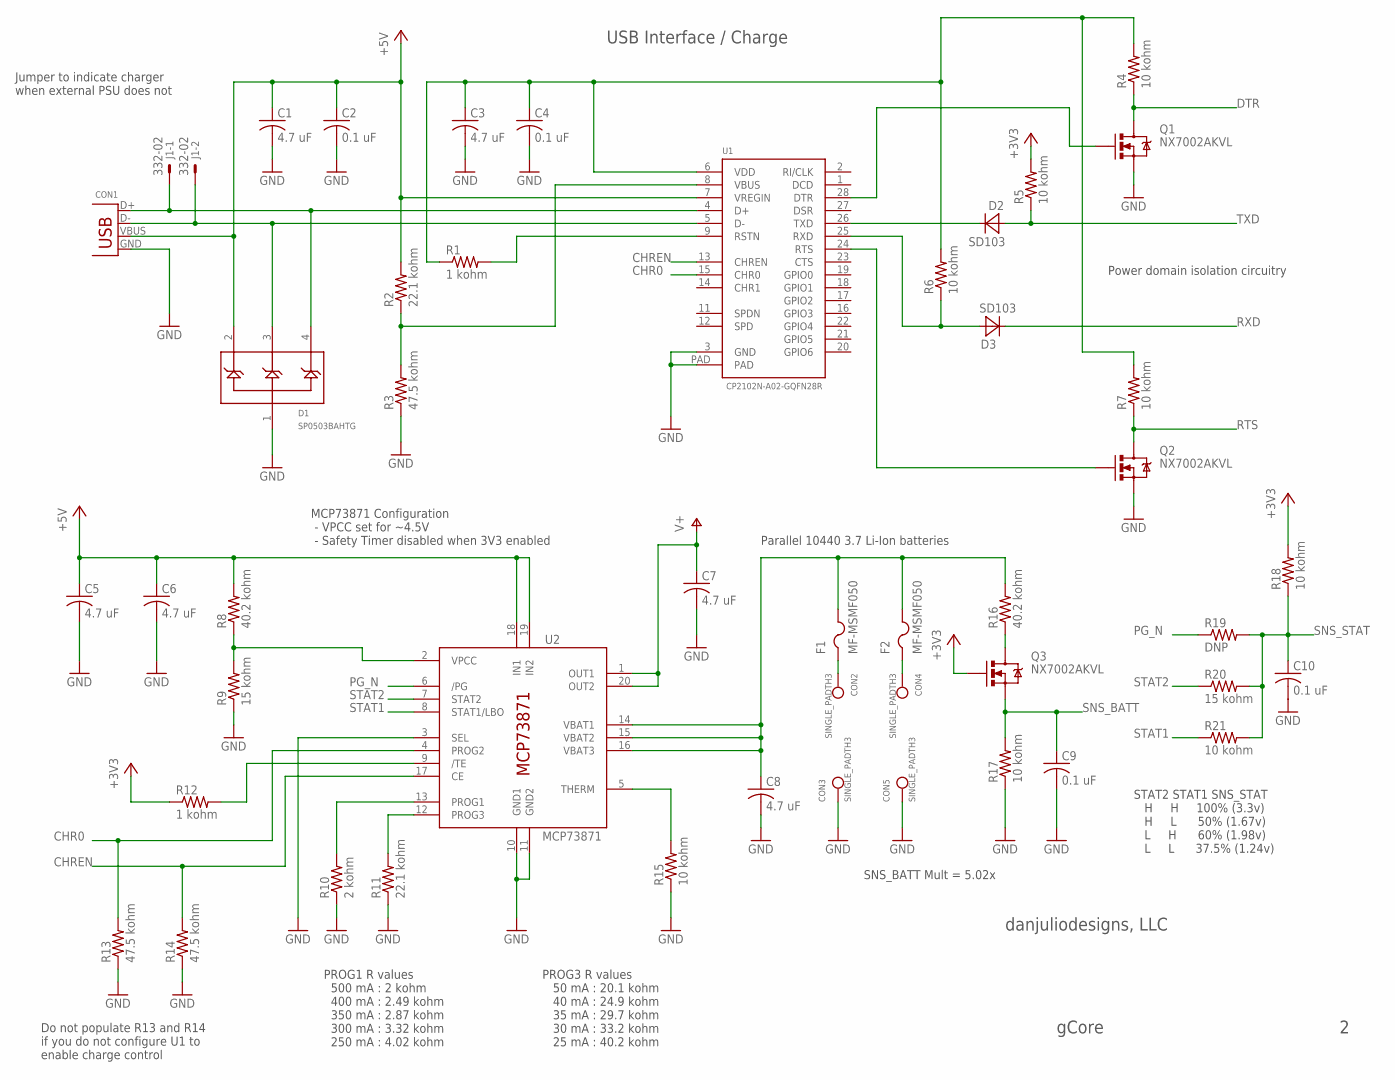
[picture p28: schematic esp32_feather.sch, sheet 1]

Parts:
C1, C3, C5, C6, C7, C8: 4.7 uF; C0603
C2, C4, C9, C10: 0.1 uF; C0603
CON1: USBMICROB; USB_MICROB_SMT
CON2, CON3, CON4, CON5: SINGLE_PADTH3; SINGLE_PAD_POWER
D1: SP0503BAHTG; SOT143
D2, D3: SD103; SOD123
F1, F2: MF-MSMF050; 1812
J1: 332-02
Q1, Q2, Q3: NX7002AKVL; SOT23-3
R1, R12: 1 kohm; R0603
R2, R11: 22.1 kohm; R0603
R3, R13, R14: 47.5 kohm; R0603
R4, R5, R6, R7, R15, R17, R18, R21: 10 kohm; R0603
R8, R16: 40.2 kohm; R0603
R9, R20: 15 kohm; R0603
R10: 2 kohm; R0603
R19: DNP; R0603
U1: CP2102N-A02-GQFN28R; QFN28
U2: MCP73871; QFN20

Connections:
+3V3: Q3.1 (G), R5.2, R12.1, R18.2; also elsewhere on the board
+5V: C1.1, C2.1, C5.1, C6.1, CON1.VBUS, D1.2 (C1), R2.2, R8.2, U1.7 (VREGIN), U2.18 (IN1), U2.19 (IN2); also elsewhere on the board
CHR0: R13.2, U1.15 (CHR0), U2.4 (PROG2)
CHREN: R14.2, U1.13 (CHREN), U2.17 (CE)
DTR: Q1.3 (D), R4.1; also elsewhere on the board
GND: C1.2, C2.2, C3.2, C4.2, C5.2, C6.2, C7.2, C8.2, C9.2, C10.2, CON1.GND, CON3.P$1, CON5.P$1, D1.1 (GND), Q1.2 (S), Q2.2 (S), R3.1, R9.1, R10.1, R11.1, R13.1, R14.1, R15.1, R17.1, U1.3 (GND), U1.PAD, U2.3 (SEL), U2.10 (GND1), U2.11 (GND2); also elsewhere on the board
unnamed: CON1.D+, D1.4 (C3), J1.1, U1.4 (D+)
unnamed: CON1.D-, D1.3 (C2), J1.2, U1.5 (D-)
unnamed: R15.2, U2.5 (THERM)
unnamed: C8.1, F1.2, F2.2, R16.2, U2.14 (VBAT1), U2.15 (VBAT2), U2.16 (VBAT3)
unnamed: R1.2, U1.9 (RSTN)
unnamed: Q1.1 (G), U1.28 (DTR)
unnamed: R8.1, R9.2, U2.2 (VPCC)
unnamed: R2.1, R3.2, U1.8 (VBUS)
unnamed: D2.C, U1.26 (TXD)
unnamed: D3.A, R6.1, U1.25 (RXD)
unnamed: Q2.1 (G), U1.24 (RTS)
unnamed: R10.2, U2.13 (PROG1)
unnamed: R11.2, U2.12 (PROG3)
unnamed: CON2.P$1, F1.1
unnamed: CON4.P$1, F2.1
unnamed: R12.2, U2.9 (/TE)
unnamed: Q3.3 (D), R16.1
PG_N: R19.1, U2.6 (/PG)
RTS: Q2.3 (D), R7.1; also elsewhere on the board
RXD: D3.C; also elsewhere on the board
SNS_BATT: C9.1, Q3.2 (S), R17.2; also elsewhere on the board
SNS_STAT: C10.1, R18.1, R19.2, R20.2, R21.2; also elsewhere on the board
STAT1: R21.1, U2.8 (STAT1/LBO)
STAT2: R20.1, U2.7 (STAT2)
TXD: D2.A, R5.1; also elsewhere on the board
V+: C7.1, U2.1 (OUT1), U2.20 (OUT2); also elsewhere on the board
VDD: C3.1, C4.1, R1.1, R4.2, R6.2, R7.2, U1.6 (VDD)

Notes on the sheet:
Parallel 10440 3.7 Li-Ion batteries
USB Interface / Charge
danjuliodesigns, LLC
gCore
PROG3 R values 50 mA : 20.1 kohm 40 mA : 24.9 kohm 35 mA : 29.7 kohm 30 mA : 33.2 kohm 25 mA : 40.2 kohm
PROG1 R values 500 mA : 2 kohm 400 mA : 2.49 kohm 350 mA : 2.87 kohm 300 mA : 3.32 kohm 250 mA : 4.02 kohm
MCP73871 Configuration - VPCC set for ~4.5V - Safety Timer disabled when 3V3 enabled
Power domain isolation circuitry
SNS_BATT Mult = 5.02x
STAT2 STAT1 SNS_STAT H H 100% (3.3v) H L 50% (1.67v) L H 60% (1.98v) L L 37.5% (1.24v)
Jumper to indicate charger when external PSU does not
Do not populate R13 and R14 if you do not configure U1 to enable charge control

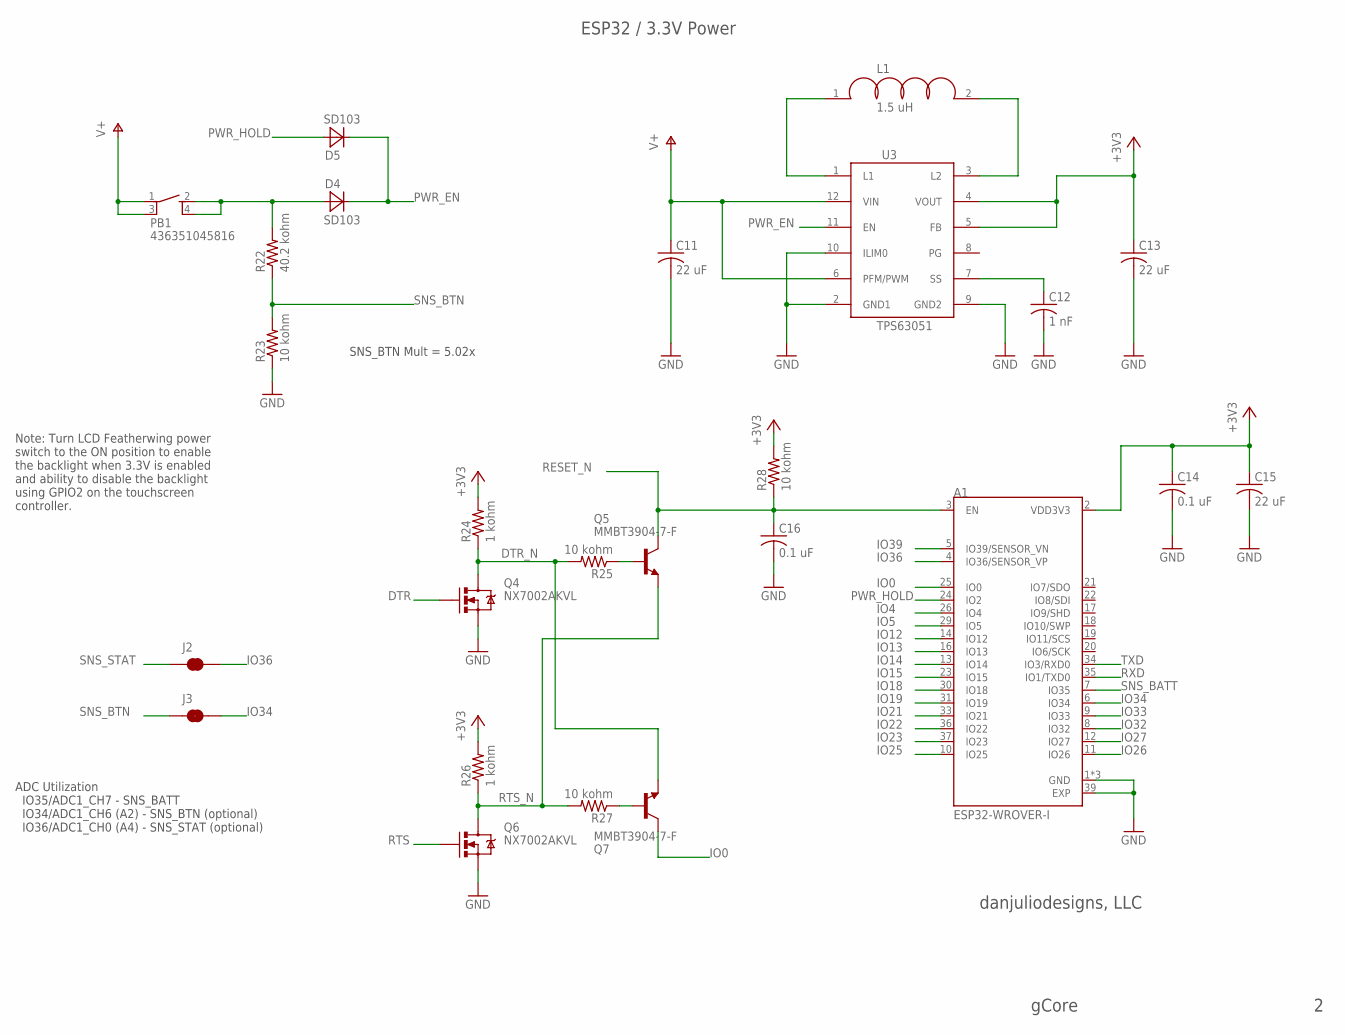
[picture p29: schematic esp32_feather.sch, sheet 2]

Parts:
A1: ESP32-WROVER-I; XCVR_ESP32-WROVER-I
C11, C13, C15: 22 uF; C0603
C12: 1 nF; C0603
C14, C16: 0.1 uF; C0603
D4, D5: SD103; SOD123
J2, J3: SJ_WIRED; SJ_2B_ADA
L1: 1.5 uH; L1008
PB1: 436351045816; WURTH_WS_TASU_TACT
Q4, Q6: NX7002AKVL; SOT23-3
Q5, Q7: MMBT3904-7-F; SOT23-BEC
R22: 40.2 kohm; R0603
R23, R25, R27, R28: 10 kohm; R0603
R24, R26: 1 kohm; R0603
U3: TPS63051; HOTROD_QFN12

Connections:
+3V3: A1.2 (VDD3V3), C13.1, C14.1, C15.1, R24.2, R26.2, R28.2, U3.4 (VOUT), U3.5 (FB); also elsewhere on the board
DTR: Q4.1 (G); also elsewhere on the board
DTR_N: Q4.3 (D), Q7.E, R24.1, R25.2
GND: A1.1 (GND), A1.15 (GND), A1.38 (GND), A1.39 (EXP), C11.2, C12.2, C13.2, C14.2, C15.2, C16.2, Q4.2 (S), Q6.2 (S), R23.1, U3.2 (GND1), U3.9 (GND2), U3.10 (ILIM0); also elsewhere on the board
IO0: A1.25 (IO0), Q7.C
IO4: A1.26 (IO4); also elsewhere on the board
IO5: A1.29 (IO5); also elsewhere on the board
IO12: A1.14 (IO12); also elsewhere on the board
IO13: A1.16 (IO13); also elsewhere on the board
IO14: A1.13 (IO14); also elsewhere on the board
IO15: A1.23 (IO15); also elsewhere on the board
IO18: A1.30 (IO18); also elsewhere on the board
IO19: A1.31 (IO19); also elsewhere on the board
IO21: A1.33 (IO21); also elsewhere on the board
IO22: A1.36 (IO22); also elsewhere on the board
IO23: A1.37 (IO23); also elsewhere on the board
IO25: A1.10 (IO25); also elsewhere on the board
IO26: A1.11 (IO26); also elsewhere on the board
IO27: A1.12 (IO27); also elsewhere on the board
IO32: A1.8 (IO32); also elsewhere on the board
IO33: A1.9 (IO33); also elsewhere on the board
IO34: A1.6 (IO34), J3.2; also elsewhere on the board
IO36: A1.4 (IO36/SENSOR_VP), J2.2; also elsewhere on the board
IO39: A1.5 (IO39/SENSOR_VN); also elsewhere on the board
unnamed: L1.1, U3.1 (L1)
unnamed: L1.2, U3.3 (L2)
unnamed: C12.1, U3.7 (SS)
unnamed: D4.A, PB1.2 (3), PB1.4, R22.2
unnamed: Q5.B, R25.1
unnamed: Q7.B, R27.1
PWR_EN: D4.C, D5.C, U3.11 (EN)
PWR_HOLD: A1.24 (IO2), D5.A
RESET_N: A1.3 (EN), C16.1, Q5.C, R28.1; also elsewhere on the board
RTS: Q6.1 (G); also elsewhere on the board
RTS_N: Q5.E, Q6.3 (D), R26.1, R27.2
RXD: A1.35 (IO1/TXD0); also elsewhere on the board
SNS_BATT: A1.7 (IO35); also elsewhere on the board
SNS_BTN: J3.1, R22.1, R23.2
SNS_STAT: J2.1; also elsewhere on the board
TXD: A1.34 (IO3/RXD0); also elsewhere on the board
V+: C11.1, PB1.1, PB1.3 (2), U3.6 (PFM/PWM), U3.12 (VIN); also elsewhere on the board

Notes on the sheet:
ESP32 / 3.3V Power
danjuliodesigns, LLC
gCore
SNS_BTN Mult = 5.02x
Note: Turn LCD Featherwing power switch to the ON position to enable the backlight when 3.3V is enabled and ability to disable the backlight using GPIO2 on the touchscreen controller.
ADC Utilization IO35/ADC1_CH7 - SNS_BATT IO34/ADC1_CH6 (A2) - SNS_BTN (optional) IO36/ADC1_CH0 (A4) - SNS_STAT (optional)

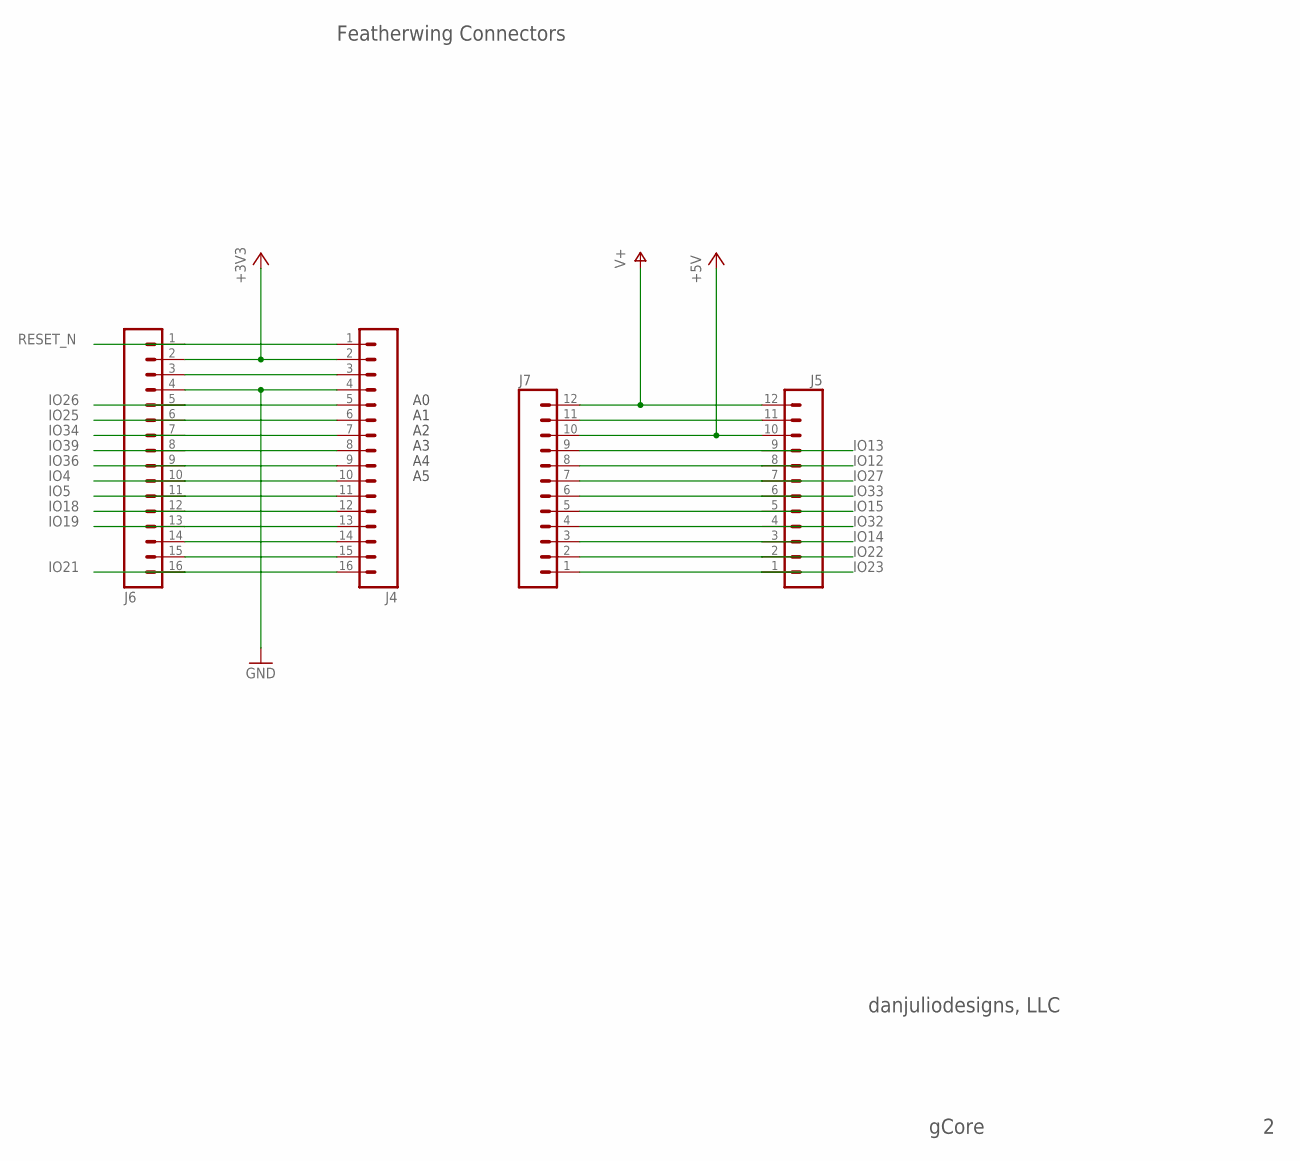
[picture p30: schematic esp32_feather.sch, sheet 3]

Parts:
J4, J6: M16PTH; 1X16
J5, J7: M12PTH; 1X12

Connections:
+3V3: J4.2, J6.2; also elsewhere on the board
+5V: J5.10, J7.10; also elsewhere on the board
FTHR_EN: J5.11, J7.11
GND: J4.4, J6.4; also elsewhere on the board
IO4: J4.10, J6.10; also elsewhere on the board
IO5: J4.11, J6.11; also elsewhere on the board
IO12: J5.8, J7.8; also elsewhere on the board
IO13: J5.9, J7.9; also elsewhere on the board
IO14: J5.3, J7.3; also elsewhere on the board
IO15: J5.5, J7.5; also elsewhere on the board
IO18: J4.12, J6.12; also elsewhere on the board
IO19: J4.13, J6.13; also elsewhere on the board
IO21: J4.16, J6.16; also elsewhere on the board
IO22: J5.2, J7.2; also elsewhere on the board
IO23: J5.1, J7.1; also elsewhere on the board
IO25: J4.6, J6.6; also elsewhere on the board
IO26: J4.5, J6.5; also elsewhere on the board
IO27: J5.7, J7.7; also elsewhere on the board
IO32: J5.4, J7.4; also elsewhere on the board
IO33: J5.6, J7.6; also elsewhere on the board
IO34: J4.7, J6.7; also elsewhere on the board
IO36: J4.9, J6.9; also elsewhere on the board
IO39: J4.8, J6.8; also elsewhere on the board
unnamed: J4.3, J6.3
unnamed: J4.14, J6.14
unnamed: J4.15, J6.15
RESET_N: J4.1, J6.1; also elsewhere on the board
V+: J5.12, J7.12; also elsewhere on the board

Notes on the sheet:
Featherwing Connectors
danjuliodesigns, LLC
gCore

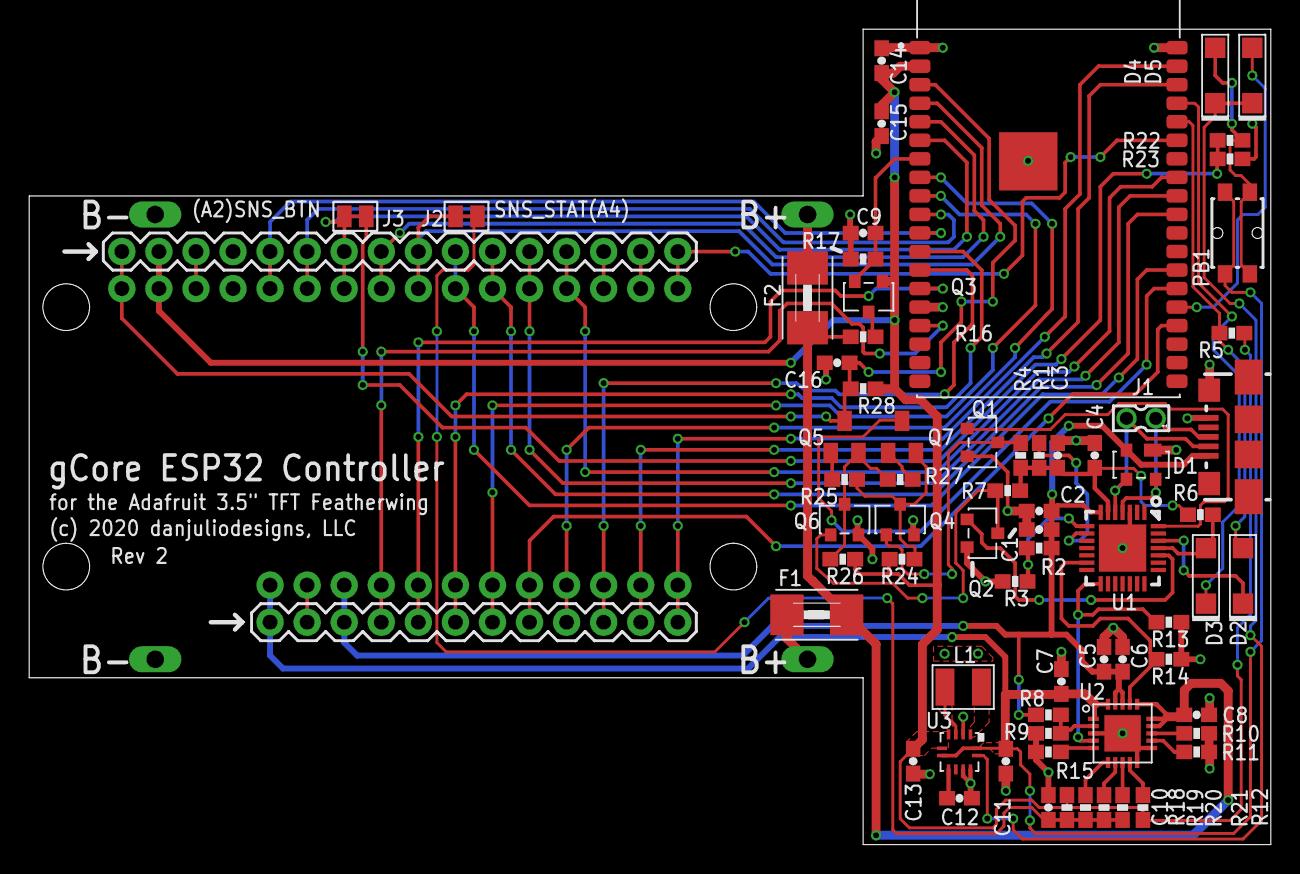
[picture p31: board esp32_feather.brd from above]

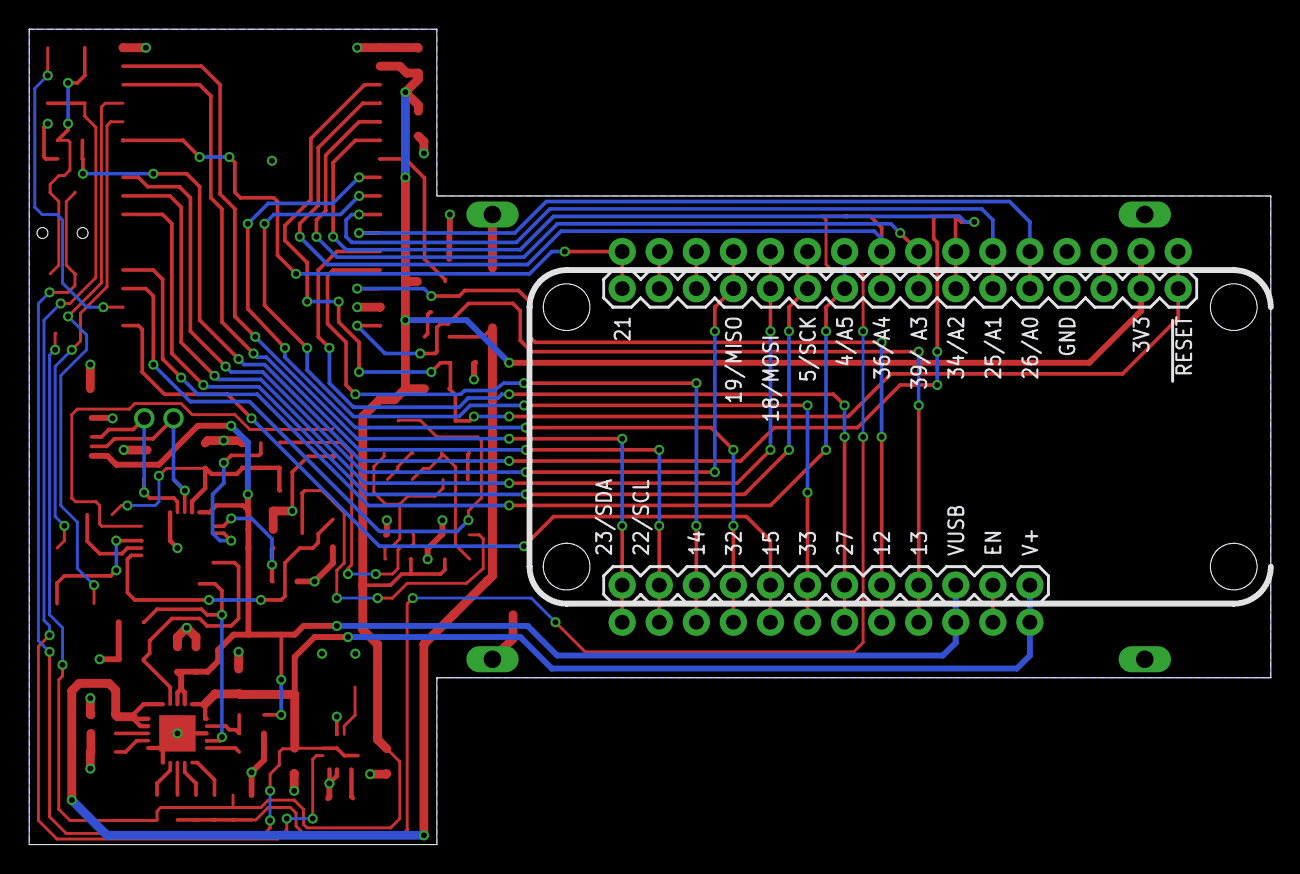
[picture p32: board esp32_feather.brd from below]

Board: 2 copper layers, 85.1 x 55.9 mm, 76 parts (2 on the bottom side), 69 nets.

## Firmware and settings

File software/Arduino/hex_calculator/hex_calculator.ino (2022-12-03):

/*
 * A simple programmers calculator with number entry and conversion between decimal 
 * and hexadecimal bases with logic functions and memory.  Inspired by the Apple OS X 
 * calculator that I often use during design and programming (but with the functionality 
 * I want...).
 * 
 * A drop-down menu allows selecting the number of bits to work with (8-64 bits
 * in 8-bit increments).  A switch selects decimal or hexadecimal operation.eSPI ported to gCore
 * 
 * This code configures the display to operate in Landscape mode.  The lv_conf.h file
 * in the LVGL library directory must be configured to match
 *   #define LV_HOR_RES_MAX          (480)
 *   #define LV_VER_RES_MAX          (320)
 *
 */
#include "SPI.h"
#include <Ticker.h>
#include <lvgl.h>



// ================================================
// USER CONFIGURATION
// ================================================
// Number display color
#define READOUT_COLOR     LV_COLOR_MAKE(0xF0, 0xB0, 0x00)
#define READOUT_COLOR_LB  LV_COLOR_MAKE(0xF0, 0x00, 0x00)

// Auto-shutdown timeout (mSec)
#define APP_INACTIVITY_TIMEOUT 120000

// Low battery warning voltage - must be higher than GCORE_LOW_BATT (which turns us off)
#define APP_LOW_BATT 3.6



// ================================================
// PROGRAM CONSTANTS AND VARIABLES
// ================================================
#define APP_GCORE_EVAL_MSEC  100
#define APP_LVGL_EVAL_MSEC   20
#define APP_INACTIVITY_COUNT (APP_INACTIVITY_TIMEOUT/APP_GCORE_EVAL_MSEC)

//
// gCore pins
//
#define SPI_SCK    5
#define SPI_MOSI   18
#define SPI_MISO   19

#define SD_CS      14



// ------------------------------------------------
// Global Variables

// LVGL
lv_disp_buf_t disp_buf;
lv_color_t buf[LV_HOR_RES_MAX * 10];

const int screenWidth = 480;
const int screenHeight = 320;

// Application evaluation timers
unsigned long gcore_prev_msec;
unsigned long lvgl_prev_msec;
unsigned long app_inactivity_count;

// Low battery flag - set the first time a low-battery condition is detected
bool low_batt_flag = false;



// ================================================
// Application subroutines
// ================================================
void note_activity()
{
  app_inactivity_count = 0;
}


bool task_timeout(unsigned long* prevT, unsigned long timeout)
{
  unsigned long curT = millis();
  unsigned long deltaT;
  
  if (curT > *prevT) {
    deltaT = curT - *prevT;
  } else {
    // Handle wrap
    deltaT = ~(*prevT - curT) + 1;
  }

  if (deltaT >= timeout) {
    *prevT = curT;
    return true;
  } else {
    return false;
  }
}



// ================================================
// Arduino entry-points
// ================================================
void setup()
{
  // Diagnostic output
  Serial.begin(115200);

  // Initialize gcore_power for power hold, battery monitoring and button soft-off
  gcore_begin();
  
  // Force the SD CS High
  pinMode(SD_CS, OUTPUT);
  digitalWrite(SD_CS, HIGH);

  // SPI setup here since it's used by both the LCD and Touchpad
  SPI.begin(SPI_SCK, SPI_MISO, SPI_MOSI);

  // Setup LVGL
  lvgl_setup();

  // Setup the initial calculator values
  calc_init();

  // Draw the display (after calculator setup)
  gui_init();

  // Finally start the app
  gcore_prev_msec = millis();
  lvgl_prev_msec = gcore_prev_msec;
  app_inactivity_count = 0;
}


void loop()
{
  uint8_t reg;
  uint16_t batt_mv;
  
  // Periodically give time to LVGL to update
  if (task_timeout(&lvgl_prev_msec, 20)) {
    lv_task_handler();
  }
  
  // Periodically check gCore
  // 1. Look for conditions to power-off
  //   a. Manual power off from button press
  //   b. Inactivity shutdown (when running on battery)
  // 2. Look for low battery condition
  //
  if (task_timeout(&gcore_prev_msec, 100)) {
    if (gcore_button_short_press() ||
        ((++app_inactivity_count >= APP_INACTIVITY_COUNT) && (gcore_get_charge_state() == 0))) {
      
      Serial.println("Power down...");
      delay(10);
      gcore_power_down();
      while (1) {};
    }
  }

  if (!low_batt_flag) {
    if (gcore_get_batt_voltage() < APP_LOW_BATT) {
      low_batt_flag = true;
    }
  }
}

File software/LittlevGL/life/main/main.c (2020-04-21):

/* gCore runs "Life"
 * 
 * A tribute to John Conway (1938-2020) who gave us "Life" and who passed away
 * while I was writing the documentation for gCore.
 *
 * This example code is in the Public Domain (or CC0 licensed, at your option.)
 *
 * Unless required by applicable law or agreed to in writing, this
 * software is distributed on an "AS IS" BASIS, WITHOUT WARRANTIES OR
 * CONDITIONS OF ANY KIND, either express or implied.
 */
#include <stdbool.h>
#include <stdio.h>
#include <stdlib.h>
#include <string.h>

#include "freertos/FreeRTOS.h"
#include "freertos/task.h"
#include "esp_freertos_hooks.h"
#include "esp_system.h"

// Application specific
#include "gcore_power.h"
#include "gui.h"
#include "life.h"

// Littlevgl specific
#include "lvgl/lvgl.h"
#include "disp_spi.h"
#include "disp_driver.h"
#include "tp_spi.h"
#include "touch_driver.h"


//
// Defines
//

// Shared SPI Bus for the TFT and Touchscreen
#define GCORE_SPI_HOST VSPI_HOST



//
// Forward declarations
//
static void IRAM_ATTR lv_tick_task(void);
static void driver_init();
static void configure_shared_spi_bus(void);


//
// Application entry point
//
void app_main() {

	// Setup gCore utility monitoring (switch, charge, battery)
	gcore_begin();
	
	// Setup LittlevGL
	lv_init();
	driver_init();
	esp_register_freertos_tick_hook(lv_tick_task);

	// Create the GUI 
	gui_init();

	// Evaluate LittlevGL (GUI containing life evaluation)
	while (1) {
		vTaskDelay(5);
		lv_task_handler();
	}
}



//
// Subroutines
//
 
static void IRAM_ATTR lv_tick_task(void) {
	lv_tick_inc(portTICK_RATE_MS);
}


static void driver_init()
{
	//
	// Interface and driver initialization
	//   Configure one SPI bus for the two devices
	//   Configure the drivers (they don't need to initialize their SPI bus)
	//
	configure_shared_spi_bus();
	disp_driver_init(false);
	touch_driver_init(false);

	//
	// Register drivers with LittlevGL
	//
	static lv_color_t buf1[DISP_BUF_SIZE];
	static lv_color_t buf2[DISP_BUF_SIZE];
	static lv_disp_buf_t disp_buf;
	lv_disp_buf_init(&disp_buf, buf1, buf2, DISP_BUF_SIZE);

	lv_disp_drv_t disp_drv;
	lv_disp_drv_init(&disp_drv);
	disp_drv.flush_cb = disp_driver_flush;
	disp_drv.buffer = &disp_buf;
	lv_disp_drv_register(&disp_drv);

	lv_indev_drv_t indev_drv;
	lv_indev_drv_init(&indev_drv);
	indev_drv.read_cb = touch_driver_read;
	indev_drv.type = LV_INDEV_TYPE_POINTER;
	lv_indev_drv_register(&indev_drv);
}


static void configure_shared_spi_bus(void)
{
	// Shared SPI bus configuration
	spi_bus_config_t buscfg = {
		.miso_io_num = TP_SPI_MISO,
		.mosi_io_num = DISP_SPI_MOSI,
		.sclk_io_num = DISP_SPI_CLK,
		.quadwp_io_num = -1,
		.quadhd_io_num = -1,
		.max_transfer_sz = DISP_BUF_SIZE * 2
	};

	esp_err_t ret = spi_bus_initialize(GCORE_SPI_HOST, &buscfg, 1);
	assert(ret == ESP_OK);

	// SPI Devices
	disp_spi_add_device(GCORE_SPI_HOST);
	tp_spi_add_device(GCORE_SPI_HOST);
}

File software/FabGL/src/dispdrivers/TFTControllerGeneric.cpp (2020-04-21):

/*
  Created by Fabrizio Di Vittorio (fdivitto2013@gmail.com) - <http://www.fabgl.com>
  Copyright (c) 2019-2020 Fabrizio Di Vittorio.
  All rights reserved.

  This file is part of FabGL Library.

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
  You should have received a copy of the GNU General Public License
  along with FabGL.  If not, see <http://www.gnu.org/licenses/>.
 */



#include <string.h>

#include "freertos/FreeRTOS.h"
#include "freertos/task.h"

#include "fabutils.h"
#include "TFTControllerGeneric.h"




#define TFT_UPDATETASK_STACK             1024
#define TFT_UPDATETASK_PRIORITY          5

#define TFT_BACKGROUND_PRIMITIVE_TIMEOUT 10000  // uS

//#define TFT_SPI_WRITE_FREQUENCY          40000000
#define TFT_SPI_WRITE_FREQUENCY          26000000
#define TFT_SPI_MODE                     SPI_MODE3
#define TFT_DMACHANNEL                   2




namespace fabgl {



// ESP32 is little-endian (in SPI, low byte of 16bit word is sent first), so the 16bit word must be converted from
//   RRRRRGGG GGGBBBBB
// to
//   GGGBBBBB RRRRRGGG
inline uint16_t preparePixel(RGB888 const & px)
{
  return ((uint16_t)(px.G & 0xe0) >> 5) |    //  0 ..  2: bits 5..7 of G
         ((uint16_t)(px.R & 0xf8)) |         //  3 ..  7: bits 3..7 of R
         ((uint16_t)(px.B & 0xf8) << 5) |    //  8 .. 12: bits 3..7 of B
         ((uint16_t)(px.G & 0x1c) << 11);    // 13 .. 15: bits 2..4 of G
}


inline RGB888 nativeToRGB888(uint16_t pattern)
{
  return RGB888(
    (pattern & 0xf8),
    ((pattern & 7) << 5) | ((pattern & 0xe000) >> 11),
    ((pattern & 0x1f00) >> 5)
  );
}


inline RGBA8888 nativeToRGBA8888(uint16_t pattern)
{
  return RGBA8888(
    (pattern & 0xf8),
    ((pattern & 7) << 5) | ((pattern & 0xe000) >> 11),
    ((pattern & 0x1f00) >> 5),
    0xff
  );
}


inline uint16_t RGBA2222toNative(uint8_t rgba2222)
{
  return preparePixel(RGB888((rgba2222 & 3) * 85, ((rgba2222 >> 2) & 3) * 85, ((rgba2222 >> 4) & 3) * 85));
}


inline uint16_t RGBA8888toNative(RGBA8888 const & rgba8888)
{
  return preparePixel(RGB888(rgba8888.R, rgba8888.G, rgba8888.B));
}


TFTController::TFTController()
  : m_spi(nullptr),
    m_SPIDevHandle(nullptr),
    m_viewPort(nullptr),
    m_controllerWidth(240),
    m_controllerHeight(320),
    m_rotOffsetX(0),
    m_rotOffsetY(0),
    m_updateTaskHandle(nullptr),
    m_updateTaskRunning(false),
    m_orientation(TFTOrientation::Rotate0),
    m_reverseHorizontal(false)
{
}


TFTController::~TFTController()
{
  end();
}


//// setup manually controlled pins
void TFTController::setupGPIO()
{
  // DC GPIO
  PIN_FUNC_SELECT(GPIO_PIN_MUX_REG[m_DC], PIN_FUNC_GPIO);
  gpio_set_direction(m_DC, GPIO_MODE_OUTPUT);
  gpio_set_level(m_DC, 1);

  // reset GPIO
  if (m_RESX != GPIO_UNUSED) {
    PIN_FUNC_SELECT(GPIO_PIN_MUX_REG[m_RESX], PIN_FUNC_GPIO);
    gpio_set_direction(m_RESX, GPIO_MODE_OUTPUT);
    gpio_set_level(m_RESX, 1);
  }

  // CS GPIO
  if (m_CS != GPIO_UNUSED) {
    PIN_FUNC_SELECT(GPIO_PIN_MUX_REG[m_CS], PIN_FUNC_GPIO);
    gpio_set_direction(m_CS, GPIO_MODE_OUTPUT);
    gpio_set_level(m_CS, 1);
  }
}


// use SPIClass
// without CS it is not possible to share SPI with other devices
void TFTController::begin(SPIClass * spi, gpio_num_t DC, gpio_num_t RESX, gpio_num_t CS)
{
  m_spi   = spi;
  m_DC    = DC;
  m_RESX  = RESX;
  m_CS    = CS;

  setupGPIO();
}


// use SPIClass
// without CS it is not possible to share SPI with other devices
void TFTController::begin(SPIClass * spi, int DC, int RESX, int CS)
{
  begin(spi, int2gpio(DC), int2gpio(RESX), int2gpio(CS));
}


// use SDK driver
// without CS it is not possible to share SPI with other devices
void TFTController::begin(int SCK, int MOSI, int DC, int RESX, int CS, int host)
{
  m_SPIHost = (spi_host_device_t)host;
  m_SCK     = int2gpio(SCK);
  m_MOSI    = int2gpio(MOSI);
  m_DC      = int2gpio(DC);
  m_RESX    = int2gpio(RESX);
  m_CS      = int2gpio(CS);

  setupGPIO();
  SPIBegin();
}


void TFTController::end()
{
  if (m_updateTaskHandle)
    vTaskDelete(m_updateTaskHandle);
  m_updateTaskHandle = nullptr;

  freeViewPort();

  SPIEnd();
}


void TFTController::setResolution(char const * modeline, int viewPortWidth, int viewPortHeight, bool doubleBuffered)
{
  char label[32];
  int pos = 0, swidth, sheight;
  int count = sscanf(modeline, "\"%[^\"]\" %d %d %n", label, &swidth, &sheight, &pos);
  if (count != 3 || pos == 0)
    return; // invalid modeline
  
  m_screenWidth  = swidth;
  m_screenHeight = sheight;
  m_screenCol    = 0;
  m_screenRow    = 0;
  
  setDoubleBuffered(doubleBuffered);
  
  m_viewPortWidth  = viewPortWidth < 0 ? m_screenWidth : viewPortWidth;
  m_viewPortHeight = viewPortHeight < 0 ? m_screenHeight : viewPortHeight;
  
  m_rot0ViewPortWidth  = m_viewPortWidth;
  m_rot0ViewPortHeight = m_viewPortHeight;
  
  resetPaintState();
  
  hardReset();
  softReset();
  
  // setup update task
  xTaskCreate(&updateTaskFunc, "", TFT_UPDATETASK_STACK, this, TFT_UPDATETASK_PRIORITY, &m_updateTaskHandle);
  
  // allows updateTaskFunc() to run
  m_updateTaskFuncSuspended = 0;
  
}


void TFTController::setScreenCol(int value)
{
  if (value != m_screenCol) {
    m_screenCol = iclamp(value, 0, m_viewPortWidth - m_screenWidth);
    Primitive p(PrimitiveCmd::Refresh, Rect(0, 0, m_viewPortWidth - 1, m_viewPortHeight - 1));
    addPrimitive(p);
  }
}


void TFTController::setScreenRow(int value)
{
  if (value != m_screenRow) {
    m_screenRow = iclamp(value, 0, m_viewPortHeight - m_screenHeight);
    Primitive p(PrimitiveCmd::Refresh, Rect(0, 0, m_viewPortWidth - 1, m_viewPortHeight - 1));
    addPrimitive(p);
  }
}


void TFTController::hardReset()
{
  if (m_RESX != GPIO_UNUSED) {
    SPIBeginWrite();

    PIN_FUNC_SELECT(GPIO_PIN_MUX_REG[m_RESX], PIN_FUNC_GPIO);
    gpio_set_direction(m_RESX, GPIO_MODE_OUTPUT);
    gpio_set_level(m_RESX, 1);
    vTaskDelay(5 / portTICK_PERIOD_MS);
    gpio_set_level(m_RESX, 0);
    vTaskDelay(20 / portTICK_PERIOD_MS);
    gpio_set_level(m_RESX, 1);

    SPIEndWrite();

    vTaskDelay(150 / portTICK_PERIOD_MS);
  }
}
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

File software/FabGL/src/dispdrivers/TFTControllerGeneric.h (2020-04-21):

/*
  Created by Fabrizio Di Vittorio (fdivitto2013@gmail.com) - <http://www.fabgl.com>
  Copyright (c) 2019-2020 Fabrizio Di Vittorio.
  All rights reserved.

  This file is part of FabGL Library.

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
  You should have received a copy of the GNU General Public License
  along with FabGL.  If not, see <http://www.gnu.org/licenses/>.
 */


#pragma once



/**
 * @file
 *
 * @brief This file contains fabgl::TFTController definition.
 */


#include <stdint.h>
#include <stddef.h>

#include "SPI.h"

#include "freertos/FreeRTOS.h"

#include "esp32-hal.h"
#include "driver/spi_master.h"

#include "fabglconf.h"
#include "fabutils.h"
#include "displaycontroller.h"


#define TFT_CASET      0x2A
#define TFT_RASET      0x2B
#define TFT_RAMWR      0x2C
#define TFT_MADCTL     0x36



namespace fabgl {



/** \ingroup Enumerations
 * @brief This enum defines TFT orientation
 */
enum class TFTOrientation {
  Rotate0,            /**< Rotate 0 degrees */
  Rotate90,           /**< Rotate 90 degrees */
  Rotate180,          /**< Rotate 180 degrees */
  Rotate270,          /**< Rotate 270 degrees */
};


/**
 * @brief Base abstract class for TFT drivers with SPI connection.
 *
 * Example:
 *
 *     fabgl::ST7789Controller DisplayController;
 *
 *     void setup() {
 *       // SCK = 18, MOSI = 23, D/C = 22, RESET = 21, no CS  (WARN: disconnect VGA connector!!)
 *       DisplayController.begin(18, 23, 22, 21, -1, VSPI_HOST);
 *       DisplayController.setResolution(TFT_240x240);
 *
 *       Canvas cv(&DisplayController);
 *       cv.clear();
 *       cv.drawText(0, 0, "Hello World!");
 *     }
 */
class TFTController : public GenericDisplayController {

public:

  // unwanted methods
  TFTController(TFTController const&) = delete;
  void operator=(TFTController const&)   = delete;

  TFTController();

  ~TFTController();

  /**
   * @brief Initializes TFT display controller with Arduino style SPIClass object
   *
   * @param spi SPIClass object.
   * @param DC GPIO of D/C signal (Data/Command).
   * @param RESX GPIO of Reset signal (can be GPIO_UNUSED).
   * @param CS GPIO of Optional select signal (can be GPIO_UNUSED). Without CS signal it is impossible to share SPI channel with other devices.
   *
   * Example:
   *
   *     fabgl::ST7789Controller DisplayController;
   *
   *     // SCK = 18, MOSI = 23, D/C = 22, RESX = 21
   *     SPI.begin(18, -1, 23);
   *     DisplayController.begin(&SPI, GPIO_NUM_22, GPIO_NUM_21);
   *     DisplayController.setResolution(TFT_240x240);
   */
  void begin(SPIClass * spi, gpio_num_t DC, gpio_num_t RESX = GPIO_UNUSED, gpio_num_t CS = GPIO_UNUSED);

  /**
   * @brief Initializes TFT display controller with Arduino style SPIClass object
   *
   * @param spi SPIClass object.
   * @param DC GPIO of D/C signal (Data/Command).
   * @param RESX GPIO of Reset signal (can be GPIO_UNUSED).
   * @param CS GPIO of optional select signal (can be GPIO_UNUSED). Without CS signal it is impossible to share SPI channel with other devices.
   *
   * Example:
   *
   *     fabgl::ST7789Controller DisplayController;
   *
   *     // SCK = 18, MOSI = 23, D/C = 22, RESX = 21
   *     SPI.begin(18, -1, 23);
   *     DisplayController.begin(&SPI, 22, 21);
   *     DisplayController.setResolution(TFT_240x240);
   */
  void begin(SPIClass * spi, int DC, int RESX = -1, int CS = -1);

  /**
   * @brief Initializes TFT display controller
   *
   * This initializer uses SDK API to get access to the SPI channel.
   *
   * @param SCK GPIO of clock signal (sometimes named SCL).
   * @param MOSI GPIO of data out signal (sometimes named SDA).
   * @param DC GPIO of D/C signal.
   * @param RESX GPIO of optional reset signal (sometimes named RESX, can be -1).
   * @param CS GPIO of optional selet signal (can be -1). Without CS signal it is impossible to share SPI channel with other devices.
   * @param host SPI bus to use (1 = HSPI, 2 = VSPI).
   *
   * Example:
   *
   *     // setup using VSPI (compatible with SD Card, which uses HSPI)
   *     // SCK = 18, MOSI = 23, D/C = 22, RESET = 21, no CS  (WARN: disconnect VGA connector!!)
   *     DisplayController.begin(18, 23, 22, 21, -1, VSPI_HOST);
   *     DisplayController.setResolution(TFT_240x240);
   */
  void begin(int SCK, int MOSI, int DC, int RESX, int CS, int host);

  void end();

  /**
   * @brief Sets TFT resolution and viewport size
   *
   * Viewport size can be larger than display size. You can pan the view using TFTController.setScreenCol() and TFTController.setScreenRow().
   *
   * @param modeline Native display reoslution. Allowed values like TFT_240x240, TFT_240x320...
   * @param viewPortWidth Virtual viewport width. Should be larger or equal to display native width.
   * @param viewPortHeight Virtual viewport height. Should be larger or equal to display native height.
   * @param doubleBuffered if True allocates another viewport of the same size to use as back buffer.
   *
   * Example:
   *
   *     DisplayController.setResolution(TFT_240x240);
   */
  void setResolution(char const * modeline, int viewPortWidth = -1, int viewPortHeight = -1, bool doubleBuffered = false);

  // abstract method of DisplayController
  void suspendBackgroundPrimitiveExecution();

  // abstract method of DisplayController
  void resumeBackgroundPrimitiveExecution();

  // abstract method of DisplayController
  NativePixelFormat nativePixelFormat() { return NativePixelFormat::RGB565BE; }

  // abstract method of DisplayController
  int getViewPortWidth()  { return m_viewPortWidth; }

  // abstract method of DisplayController
  int getViewPortHeight() { return m_viewPortHeight; }

  // abstract method of DisplayController
  int getScreenWidth()    { return m_screenWidth; }

  // abstract method of DisplayController
  int getScreenHeight()   { return m_screenHeight; }

  /**
   * @brief Set initial left column of the viewport
   *
   * Use this method only when viewport is larger than display size.
   *
   * @param value First column to display
   */
  void setScreenCol(int value);

  /**
   * @brief Set initial top row of the viewport
   *
   * Use this method only when viewport is larger than display size.
   *
   * @param value First row to display
   */
  void setScreenRow(int value);

  /**
   * @brief Gets initial left column of the viewport
   *
   * @return First column displayed
   */
  int screenCol() { return m_screenCol; }

  /**
   * @brief Gets initial top row of the viewport
   *
   * @return First row displayed
   */
  int screenRow() { return m_screenRow; }

  void readScreen(Rect const & rect, RGB888 * destBuf);

  /**
   * @brief Performs display hardware and software
   */
  void reset() { hardReset(); softReset(); }
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

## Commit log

2020-04-21 Initial checkin
    [esp32_feather.brd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]
2020-05-23 Update readme files
    Added unused GPIO, link to hackaday.io project and new info about issues with battery balancing.
2022-06-27 Fixed bug in touchscreen driver
    [stmpe610.c]

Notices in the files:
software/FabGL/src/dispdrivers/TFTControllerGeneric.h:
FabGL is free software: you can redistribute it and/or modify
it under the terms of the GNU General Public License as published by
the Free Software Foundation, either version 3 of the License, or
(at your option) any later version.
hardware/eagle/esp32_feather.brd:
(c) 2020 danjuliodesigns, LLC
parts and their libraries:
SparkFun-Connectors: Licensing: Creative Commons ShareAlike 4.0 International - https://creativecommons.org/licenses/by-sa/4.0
